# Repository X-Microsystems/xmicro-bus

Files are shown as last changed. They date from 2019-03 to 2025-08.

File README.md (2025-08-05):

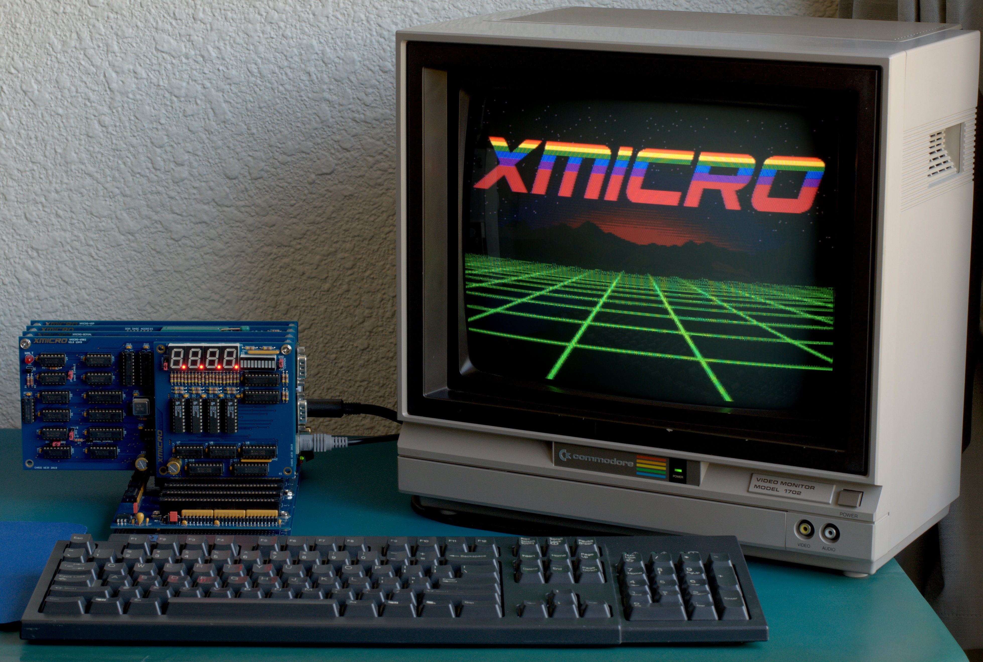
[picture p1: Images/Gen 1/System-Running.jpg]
XMICRO System Running

# XMICRO: A Modular 8-bit Microcomputer System
The XMICRO project began in 2017 as a hobby retrocomputer. Descending from a minimal 6502-based breadboard computer, the decision was made to create a platform which doesn't depend on any particular CPU architecture. In this way, many CPUs could be used for experimentation without the need to create an entire computer system around each one. The name XMICRO, meaning "variable microarchitecture", is a nod toward technology company names of the microcomputer revolution such as Zilog.

In 2020, the project was re-engineered from the ground up. This second generation of hardware improved the performance, reliability, and modularity of all parts of the system.

## Current State
The [XMICRO Bus Specification](Documentation/XMICRO%20Bus%20Specification.pdf) is not yet finalized, however many hardware components have been created which make up a functional 6502-based microcomputer. These include:
* [XMICRO-BP8](https://github.com/X-Microsystems/xmicro-bp8): 8-slot backplane
* [XMICRO-6502](https://github.com/X-Microsystems/xmicro-6502): W65C02 CPU card
* [XMICRO-MEMORY](https://github.com/X-Microsystems/xmicro-memory): 1MB RAM, 8kB ROM primary memory card
* [XMICRO-CF](https://github.com/X-Microsystems/xmicro-cf): CompactFlash storage and RTC card
* [XMICRO-SERIAL](https://github.com/X-Microsystems/xmicro-serial): Dual RS-232 and PS/2 communications card
* [XMICRO-VDP](https://github.com/X-Microsystems/xmicro-vdp): Yamaha V9958 video card

## Generation 2 Hardware Photos
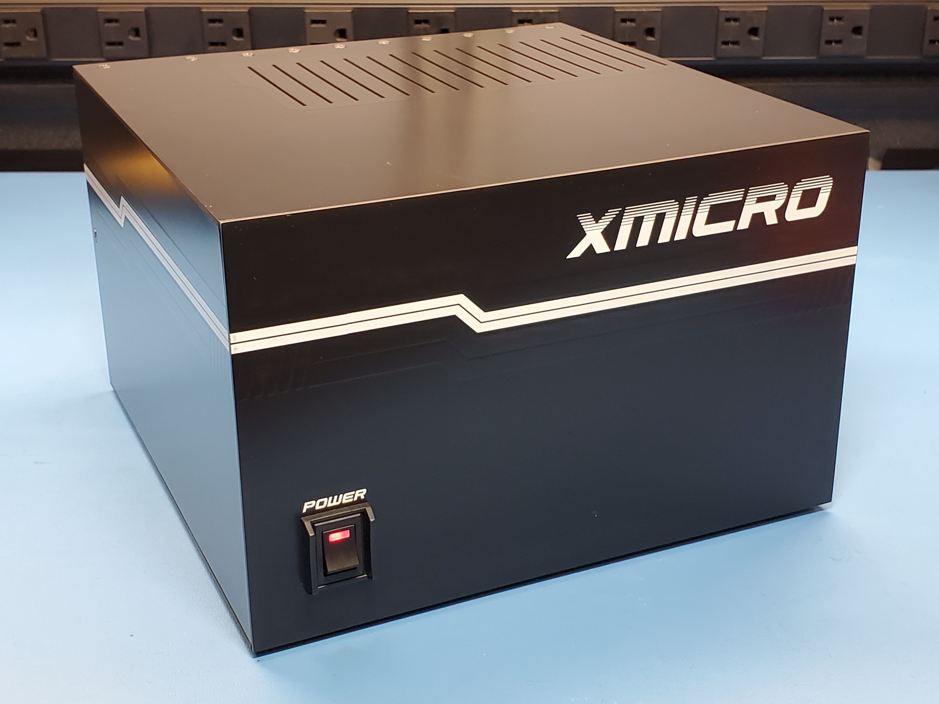
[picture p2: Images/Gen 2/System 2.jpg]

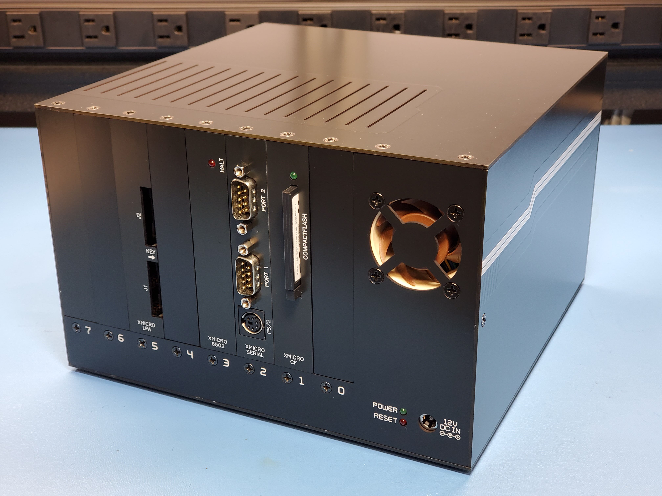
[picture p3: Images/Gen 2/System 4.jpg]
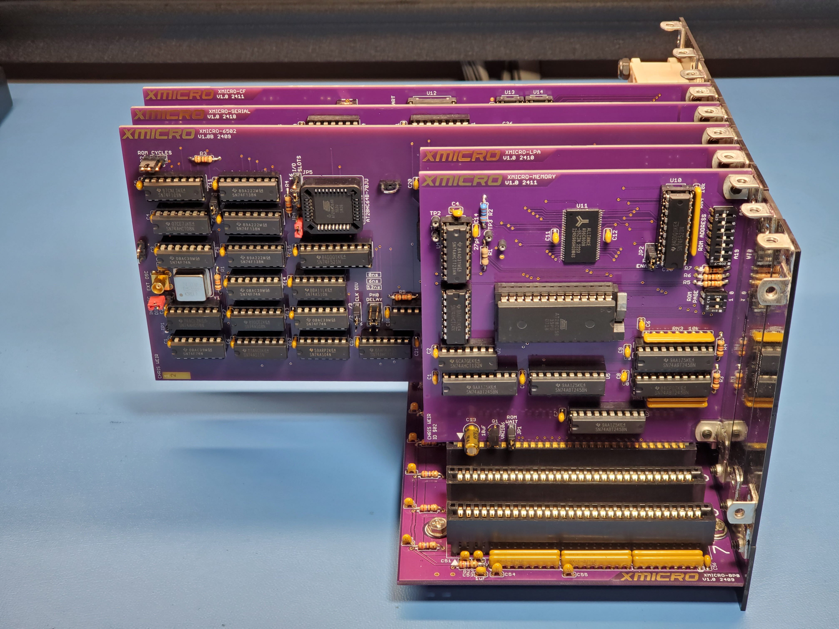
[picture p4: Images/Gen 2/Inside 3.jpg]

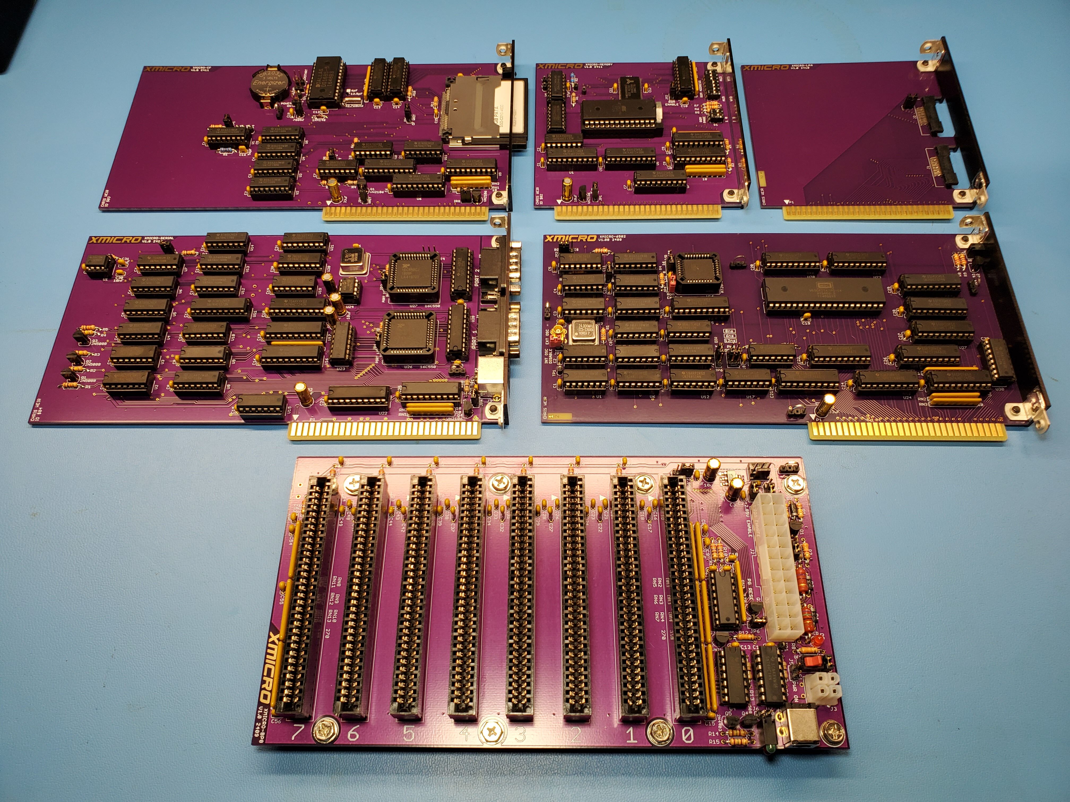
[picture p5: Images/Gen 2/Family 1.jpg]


## Generation 1 Hardware Photos
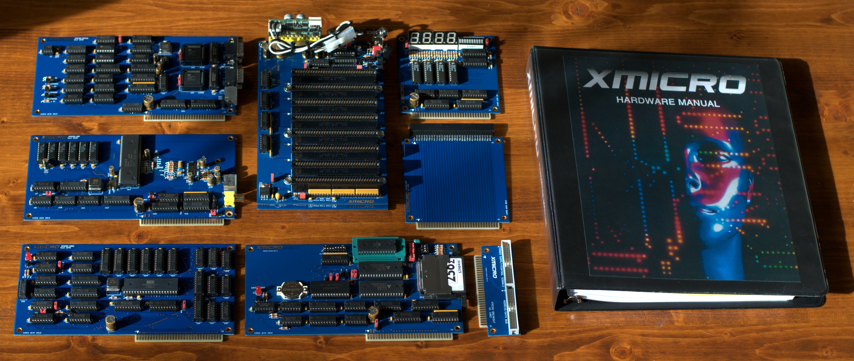
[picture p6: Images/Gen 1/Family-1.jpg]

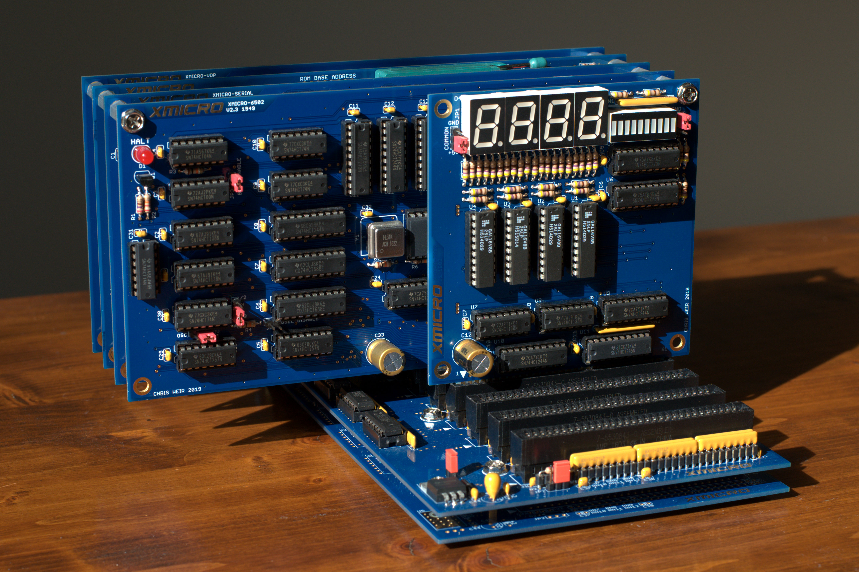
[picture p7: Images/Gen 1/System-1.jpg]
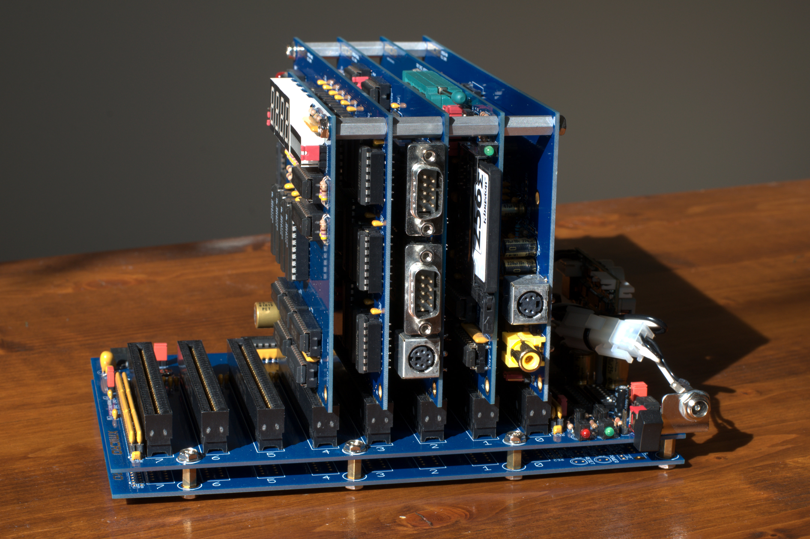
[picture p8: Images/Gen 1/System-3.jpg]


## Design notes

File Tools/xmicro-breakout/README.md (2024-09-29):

# XMICRO-BREAKOUT
Card for breaking out all signals on the [XMICRO bus](https://github.com/x-microsystems/xmicro-bus) to 0.1" pin headers. Can be used with ribbon cables and the included breadboard module for prototyping on a functional system.

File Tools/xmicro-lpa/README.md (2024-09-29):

# XMICRO-LPA

HP/Agilent logic analyzer adapter for the [XMICRO bus](https://github.com/x-microsystems/xmicro-bus). Breaks out all signals to high-density Mictor connectors.

[Datasheet](Documentation/XMICRO-LPA.pdf)

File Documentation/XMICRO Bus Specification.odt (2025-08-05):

Technical Specification

Copyright © 2017-2024 X-Microsystems

Permission is hereby granted, free of charge, to any person obtaining a copy of this specification and associated documentation files (the “Specification”), to deal in the Specification without restriction, including without limitation the rights to use, copy, modify, merge, publish, distribute, sublicense, and/or sell copies of the Specification, and to permit persons to whom the Specification is furnished to do so, subject to the following conditions:

The above copyright notice and this permission notice shall be included in all copies or substantial portions of the Specification.

THE SPECIFICATION IS PROVIDED “AS IS”, WITHOUT WARRANTY OF ANY KIND, EXPRESS OR IMPLIED, INCLUDING BUT NOT LIMITED TO THE WARRANTIES OF MERCHANTABILITY, FITNESS FOR A PARTICULAR PURPOSE AND NONINFRINGEMENT. IN NO EVENT SHALL THE AUTHORS OR COPYRIGHT HOLDERS BE LIABLE FOR ANY CLAIM, DAMAGES OR OTHER LIABILITY, WHETHER IN AN ACTION OF CONTRACT, TORT OR OTHERWISE, ARISING FROM, OUT OF OR IN CONNECTION WITH THE SPECIFICATION OR THE USE OR OTHER DEALINGS IN THE SPECIFICATION.

Tables

Figure 2-1: Read Operation Timing 6

Figure 2-2: Write Operation Timing 6

Figure 2-3: Bus Arbitration Sequence 7

Figure 5-1: Card Physical Dimensions 15

Figure 5-2: Backplane Physical Dimensions 17

Table A-1: Card ID Assignments 19

Figures

Figure 2-1: Read Operation Timing 6

Figure 2-2: Write Operation Timing 6

Figure 2-3: Bus Arbitration Sequence 7

Figure 5-1: Card Physical Dimensions 15

Figure 5-2: Backplane Physical Dimensions 17

# General Description

## Features

- Modular Design
- CPU Architecture Independence
- 8-bit Data Field Width
- 1 Megabyte Memory Address Range
- Discrete I/O Address Range
- Asynchronous Data Transfer
- Multiple Masters
- Automatic Resource Allocation
- Hardware Self-Discovery
- ATX Power Supply Compatibility
- Fully Open-source

## Overview

The XMICRO Bus is a modular platform for building microcomputer systems. Discrete modules called “cards” communicate with one another through this bus over a backplane. Each card slot on the backplane is assigned a 256-byte address space and an interrupt request line. This uniform resource allocation allows most cards to be installed in the system with little or no special hardware configuration. Another advantage of this is the ability to use multiple identical cards in the same system without conflicts. The XMICRO Bus is designed to operate without reliance on any special CPU architecture features, such that most 8-bit microprocessors can be adapted to work with other devices designed for the bus.

An XMICRO system consists of the following elements:

- Backplane
- Primary Master
- Secondary Masters
- Slaves

A Backplane is the basis of any system. In its simplest form, the backplane handles power and signal distribution, decodes I/O addresses, and provides a power-on reset signal. Each backplane contains a number of slots, into which cards may be inserted to build and expand the system. More complex implementations may add significantly more functionality, including peripherals or an onboard CPU.

A Primary Master is a device which acts as the default system controller. Typically this will be the main CPU card. Primary masters must default to this operation unless the bus is requested by another device. Primary masters handle interrupt signals and bus requests. A system must have exactly one primary master installed.

A Secondary Master is a device with the ability to act as a temporary system controller. This is used for direct memory access by the secondary master.

A Slave is a device with no ability to control the system. Slaves are only capable of being read or written to under the command of a master.

Note: The master/slave designation is used only as a broad classification of the functionality of a device. It may be used to refer to either a discrete subsystem or a card as a whole. For example, a coprocessor card may have some control/status registers that can be accessed by the master. Those registers act as a slave device when being read or written to. When the coprocessor later takes control of the bus and directly accesses memory, it is acting as a master.

## Definitions

### System Terminology

Backplane: The central component of the system which provides bus power and signals to all devices

Motherboard: A subtype of backplane containing an integrated Primary Master

Extended backplane: Any backplane with greater than 8 slots

Slot: A uniquely identified position on a backplane where a card may be installed, and the associated set of allocated resources.

Card: A discrete module which interfaces with a backplane through a slot

Master: The current active system controller. This could be either the Primary Master or a Secondary Master

Slave: A device capable of being read or written to by the master.

### Signal Notation

1. Active-low signals are denoted by an OVERLINE.
2. A range of similar signals are referred to collectively using the format A<19..0>. This example is an abbreviation of signals A19 through A0.
3. Table 1-1 lists the terminology used to describe signal states.

Table 1-1: Signal State Terminology

Term | State (Active-high Signal) | State (Active-low Signal)
Asserted | 1, High | 0, Low
Deasserted | 0, Low | 1, High
Released | Z, High-impedance | Z, High-impedance

### Numerical Notation

1. All hexadecimal numbers are indicated by a leading dollar sign ($).
2. All address values are referenced using hexadecimal notation.
3. Numerical digits are substituted with “X” to indicate that any possible value is applicable.
4. I/O resource addresses use a two-digit hexadecimal value formatted as $X00, where X indicates a variable slot number. This notation is used because I/O devices only assess the least-significant eight address bits. See 3.1.2 I/O.
5. Memory addresses use a 5-digit hexadecimal value corresponding to the values of A<19..0>. Example: $01234

# Signaling

## Signal Lines

### Address Lines (A<19..0>)

Twenty unidirectional lines driven by the master to specify a memory or I/O location. Unused address lines must be held at a logic 0 state. Where a master implements bus arbitration (See 2.4 Bus Arbitration), A<19..0> must be capable of entering a high-impedance state.

### Data Lines (D<7..0>)

Eight bidirectional lines which carry information between master and slave devices. See 2.3 Data Transfers.

### Read Strobe (RD)

Asserted by the master to indicate that the addressed slave device may place data on the data lines. The data bus is read by the master at the rising edge of RD. See 2.3 Data Transfers.

### Write Strobe (WR)

Asserted by the master to indicate that it has placed data on the data lines. The data bus should be read by the addressed slave device at the rising edge of WR. See 2.3 Data Transfers.

### I/O Select (IOSEL)

Asserted by the master to access the backplane’s card I/O address space. When asserted, A<19..8> determine which backplane slot is being addressed, and the backplane asserts the CSX signal for that slot. See 3.1 Address Spaces.

### Card Select – Slot X (CSX)

This slot-specific signal is driven by the backplane to indicate that the I/O address space is selected, and the current address is within the range of the slot’s allocated I/O address space. While this signal is asserted, A<19..8> may be ignored by the slave card because their state is known. This is a discrete signal for each card slot. See 2.2 Address Signaling and 3.1 Address Spaces.

### Main Memory Inhibit (INH)

This open-collector signal is used to inhibit general-purpose main memory. When INH is asserted, main memory must be prevented from reading or writing data, or driving the bus. This allows cards to make special-purpose memory available without reconfiguring or replacing the entire memory system. As this signal is typically derived from and therefore becomes stable after other Group A signals, its use may necessitate additional bus cycle time. INH has no effect on I/O operations. See 3.1.1 Memory.

### Wait (WAIT)

This open-collector line is asserted by the addressed slave device to indicate that the data transaction in progress is not yet ready to be completed. If WAIT is asserted concurrently with RD or WR, the master must hold all of its Group A signals in their current state until after WAIT is released. It is recommended that devices requiring greater than 100ns access time use this signal. See 2.3 Data Transfers.

### Reset (RST)

This open-collector signal resets the system and initializes it to a predictable state. During the power-on sequence, this signal should be asserted by the backplane until at least 100ms after all power supply rails have stabilized. RST may be used by any device for initialization.

### Bus Request (BUSRQ)

This open-collector signal is asserted by a secondary master to request control of the bus. When the primary master is ready to release control of the bus, it will assert BUSAK. See 2.4 Bus Arbitration.

### Bus Acknowledge (BUSAK)

This signal is asserted by the primary master to indicate that it has released all Group A bus signals for control by a secondary master. The secondary master may only control the bus while this signal is asserted. See 2.4 Bus Arbitration.

### Halt (HALT)

This status line is asserted by the primary master to indicate to that it is in a halted state and waiting for an interrupt. Not to be confused with WAIT.

### Interrupt Request – Slot X (IRQX)

This slot-specific line is asserted by a card to indicate that it requires the primary master’s attention. This allows for interrupt vectoring and prioritization based on card position. This is a level-triggered interrupt signal. This is a discrete signal for each card slot. See 2.5.1 Level-triggered Interrupts.

### Summary Interrupt (SINT)

This open-collector signal is asserted by the backplane while any IRQX line is asserted. Therefore, this is a level-triggered interrupt signal. This signal is provided by the backplane and is not to be driven directly by a card.

### Vectored Interrupt Lines (V<7..0>)

These eight lines correspond to the IRQX signal of slots 7..0 on a backplane. They are used by the primary master for interrupt prioritization and vectoring. A primary master may accept these signals as discrete interrupts from the first eight slots. These signals are provided by the backplane and are not to be driven directly by a card. See 3.3.1 Vectored Interrupts.

### Non-maskable Interrupt (NMI)

Open-collector edge-triggered interrupt signal. Its implementation may vary considerably between primary masters, so it is recommended that this signal be optional on any card using it. NMI should only be used for special signals requiring the immediate attention of the primary master and priority over all other interrupts. Some examples could be memory errors, power failure, or video timing. See 2.5.2 Edge-triggered Interrupts and 3.3.2 Non-maskable Interrupt.

### System Clock (CLK)

This signal is the main system clock. Care should be taken to ensure it is a clean square wave. Its frequency and duty cycle are not defined. The primary master should typically provide this signal, however it may optionally be provided by another card such as a video card. It is recommended that primary masters do not strictly require externally generated clock signals to function. Any card capable of driving this signal must have an option to disable it, to prevent conflicts with other cards. Use of this signal for purposes that may restrict the system’s compatibility with other devices is strongly discouraged.

### Instruction Fetch (FETCH)

This signal is asserted by the primary master to indicate that the current read/write operation is an instruction fetch. This can be used by coprocessors or debuggers for synchronization and analysis. Implementation of this signal is optional.

### Power Supply Rails (+12V, +5V, +5VSB +3.3V, 0V, -12V)

These non-signal lines supply power to the bus. Current capacity is defined by the individual backplane’s specifications, as well as 4.2 Connectors. See 4.3 Power Supply.

Table 2-1: Signal Sources

Group | Signal | Driver | Receiver
A Information | A<19..0> | Master | Any
| D<7..0> | Master (WR), Slave (RD) | Slave (WR), Master (RD)
| RD | Master | Any
| WR | Master | Any
| IOSEL | Master | Backplane, Memory Systems
| CSX | Backplane | Cards
| INH | Any | Memory Systems
B Control | WAIT | Slave | Master
| RST | Any | Any
| BUSRQ | Secondary Master | Primary Master
C Status | BUSAK | Primary Master | Secondary Master
| HALT | Primary Master | Any
| FETCH | Primary Master | Any
| CLK | Master (Typically) | Any
D Interrupt | IRQX | Any | Primary Master
| SINT | Backplane | Primary Master
| V<7..0> | Backplane | Primary Master
| NMI | Any | Primary Master
E Supply | +12V | Backplane | Any
| +5V | Backplane | Any
| +5VSB | Backplane | Any
| +3.3V | Backplane | Any
| 0V | Backplane | Any
| -12V | Backplane | Any

## Address Signaling

Table 2-2 contains a sample of address signal relationships. A<19..0> and IOSEL are driven by the master, and CSX signals are asserted by the backplane in response. See 3.1 Address Spaces.

Table 2-2: Address Signal Relationships

A<19..0> | IOSEL | CSX (Slot 0) | CSX (Slot 1) | CSX (Slot 2)
$XXXXX | 1 | 1 | 1 | 1
$000XX | 0 | 0 | 1 | 1
$001XX | 0 | 1 | 0 | 1
$002XX | 0 | 1 | 1 | 0

## Data Transfers

Data are transferred asynchronously in 8-bit words (bytes). RD/WR may only be asserted while the address lines A<19..0>, IOSEL, and CSX are valid and stable, and must never be asserted simultaneously. During a read operation, the addressed slave places data on D<7..0>, which is read by the master at the rising edge of RD. During a write operation, the master places data on D<7..0>, which is read by the slave at the rising edge of WR.

The addressed slave may optionally assert WAIT during a data transfer to temporarily pause the sequence until it is ready to send or receive data. During this time, the master must not change the state of A<19..0>, IOSEL, CSX, RD, WR, or D<7..0>. When WAIT is high, the master may complete the transfer sequence.

Table 2-3: Data Transfer Timing Parameters

No. | Symbol | Parameter | Min. | Max.
1 | Tas | Address setup time prior to RD/WR falling edge | 10ns | —
2 | Tah | Address hold time after RD/WR rising edge | 10ns | —
3 | Tds | Data setup time prior to RD/WR rising edge | 20ns | —
4 | Tdhr | Data hold time after RD rising edge | 10ns | 30ns
5 | Tdhw | Data hold time after WR rising edge | 10ns | 30ns
6 | Twl | WAIT falling edge delay after RD/WR falling edge | 0ns | 40ns
7 | Twh | RD/WR rising edge delay after WAIT rising edge | 0ns | —

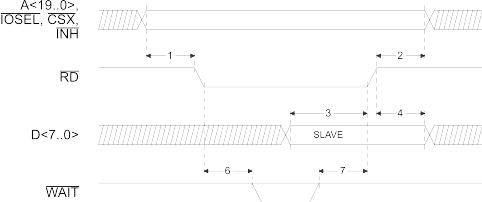
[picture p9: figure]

Figure 2-1: Read Operation Timing

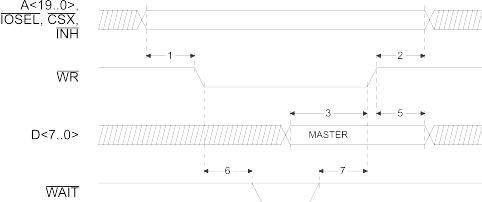
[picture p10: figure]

Figure 2-2: Write Operation Timing

## Bus Arbitration

In the system’s default state, the primary master has full control of the system bus. By asserting the BUSRQ line, a secondary master may request to temporarily take over control of some signals in order to directly access memory or I/O devices. When BUSRQ is asserted, the primary master gracefully hands over control of Group A signals.

The BUSAK signal indicates that the primary master has placed its Group A signals in a high-impedance state. These signals may be driven by a secondary master only while BUSAK is asserted. In order to prevent invalid data transfers, the primary master must remain in this high-impedance state until BUSRQ is released.

To avoid bus contention, secondary masters should wait for a command from the primary master before initiating a bus request, and must not initiate a bus request until the BUSRQ signal is no longer asserted by another device.

A typical bus arbitration sequence is as follows:

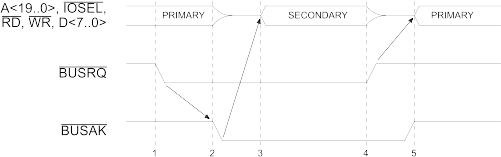
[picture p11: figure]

Figure 2-3: Bus Arbitration Sequence

1. A secondary master asserts the BUSRQ line.
2. The primary master, at its discretion, releases its Group A signals and asserts BUSAK.
3. The secondary master begins driving its Group A signals.
4. The secondary master, at its discretion, releases its Group A signals and releases BUSRQ.
5. The primary master deasserts BUSAK and resumes driving its Group A signals.

## Interrupts

Each card’s interrupt signals must default to a disabled state upon reset, such that they must be enabled through software before the card will assert them.

### Level-triggered Interrupts

Level-triggered interrupt signals (IRQX, V<7..0>, SINT) must be asserted by a device until it no longer requires the primary master’s attention. A level-triggered interrupt signal which has been asserted and released before it was serviced may be disregarded.

### Edge-triggered Interrupts

Edge-triggered interrupt signals (NMI), as the name implies, are only sensitive to a falling edge. The state of the signal has no bearing on whether an edge-triggered interrupt should be serviced.

# System Operation

## Address Spaces

The system is divided into two discrete address spaces – “Memory” and “I/O”.

1. When IOSEL is not asserted, the memory address space is selected and read/write operations apply to memory devices.
2. When IOSEL is asserted, the I/O address space is selected and read/write operations apply to I/O devices.

### Memory

There are two types of memory that can be added to a system:

1. “Main Memory” is memory that is accessible when INH is not asserted. It is recommended that only one device manages main memory in a system. Main memory is typically populated with general-purpose RAM.
2. “Override Memory”, when it is addressed, asserts the INH signal to disable main memory devices occupying the desired location. In this way, specialized memory devices may be added to a system without the need to reconfigure the main memory subsystem. In cases where INH is used, the main memory located at those addresses should be considered invalid.

### I/O

1. Each card slot on a backplane is assigned 256 bytes of I/O address space, beginning at I/O address $00000. Each 256-byte block of I/O addresses is assigned to a slot number equal to the value of A<19..8>. For example, Slot 0 addresses are located from $00000-$000FF, Slot 1 from $00100-$001FF, etc.
2. When a slot’s I/O block is addressed by the master, the backplane asserts the CSX signal for that card.
3. CSX indicates to a slave that it is being addressed, and that A<7..0> contain the address to be accessed. Slave devices may only use A<7..0> for addressing purposes, and A<19..8> must be ignored by slaves during I/O operations.
4. A backplane’s I/O decoding logic must ignore any I/O address bits that are not required to access the number of implemented slots.

## Reserved Addresses

Addresses $XFC-$XFF are reserved for special bus functions. These should not be used except as described in Table 3-1.

Table 3-1: Reserved Addresses

Address | Purpose
$XFC | Reserved
$XFD | Reserved
$XFE | Reserved
$XFF | Card ID

### Card IDs

Each card should present an identification value at address $XFF which is unique to that type of card within the system. Identical cards should have identical IDs. Cards may be assigned a permanent ID as part of the XMICRO bus specification. Refer to Appendix A for Card ID assignments.

## Interrupts

Interrupts provide cards with a means of requesting the attention of the primary master. Since interrupt schemes vary considerably between CPUs, the implementation of interrupts in an XMICRO system is relatively loosely defined.

When an interrupt signal is asserted, it is expected that the primary master will respond to it as soon as possible. Table 3-2 lists all interrupt signals on the bus, in order from highest to lowest priority. When multiple interrupt signals are being asserted simultaneously, they should be assessed in order from highest to lowest priority.

Table 3-2: Interrupt Signal Priority

Signal | Priority
NMI | Highest
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
SINT | Lowest

### Vectored Interrupts

IRQX is asserted by cards as a general-purpose interrupt request. While any card’s IRQX line is asserted, SINT is also asserted by the backplane as a summary of all interrupt requests.

Signals V<7..0> are connected on the backplane to the corresponding IRQX of slot 7..0. On extended backplanes, implementation of IRQX on slot 8 and higher is optional. The backplane may use IRQX on these slots to assert a summary interrupt (SINT) with no vector signals (V<7..0>) asserted.

### Non-maskable Interrupt

NMI is a special interrupt intended for timing-sensitive operations. It has a higher priority than any other interrupt. Where possible, a primary master should immediately respond to an NMI, including interrupting an in-progress interrupt service routine. No other interrupts should interrupt an NMI service routine.

Due to hardware limitations, some primary masters may not be capable of overriding an interrupt routine in progress. In this case, NMI should be serviced as soon as possible.

# Electrical Specifications

## Signal Lines

### Signal Characteristics

1. A receiver must recognize a voltage of ≤ 0.8V as a logic 0, and a voltage of ≥ 2.0V as a logic 1.
2. The minimum sink current capability of any driver on any line must be 20mA at 0.5V. Further, it is recommended that drivers with minimum source capability of 20mA at 2.4V be used.

Table 4-1: Bus Driver and Receiver Characteristics

Signal | Driver Topology | Receiver Hysteresis
A<19..0> | Tri-state | Not Required
D<7..0> | Tri-state | Not Required
RD | Tri-state | Not Required
WR | Tri-state | Not Required
IOSEL | Tri-state | Not Required
CSX | Push-pull | Not Required
BUSAK | Push-pull | Not Required
HALT | Push-pull | Not Required
FETCH | Push-pull | Not Required
CLK | Push-pull | Not Required
INH | Open-collector | Required
WAIT | Open-collector | Required
RST | Open-collector | Required
BUSRQ | Open-collector | Required
NMI | Open-collector | Required
IRQX | Open-collector | Not Required
SINT | Open-collector | Not Required
V<7..0> | Open-collector | Not Required

### Signal Integrity

For all signal lines, care must be taken to maintain high-speed signal integrity.

1. A card should add no more than 2” of total conductor length to any bus signal.
2. A card should present no more than 25pF capacitance to any bus signal.

### Termination

1. When no device is driving a bus line, that line must be pulled to a high state by the backplane.
2. The combined DC current of all bus terminations must not exceed 22mA on any signal line.
3. The recommended active termination scheme for all bus signal lines is a 270Ω resistor to +2.85V at each end of the backplane.

## Connectors

### Backplane Interconnects

1. Backplanes must be fitted with female 62-position dual-row card edge connectors with a 0.1” contact pitch, designed for 0.0625” card thickness. TE Connectivity 7-5530843-0 or equivalent is recommended. Each of these connectors is considered a discrete slot.
2. Cards must be fitted with male card-edges compatible with the specified backplane connectors and conforming to physical specifications outlined in 5.1 Cards.
3. The average current on any backplane connector pin must not exceed 2A. The recommended maximum current on backplane connectors is 1A for supply pins and 100mA for all other pins. If lower than these values, maximum design current for each rail must be specified in the included documentation for a backplane, or on the backplane PCB.
4. No XMICRO bus signal may be delivered between any two devices except by these backplane interconnects.

Table 4-2: Backplane Interconnect Pinout

Pin | Signal | Pin | Signal
1 | +12V | 2 | +3.3V
3 | 0V | 4 | 0V
5 | +5V | 6 | +5V
7 | -12V | 8 | +5VSB
9 | CSX | 10 | RST
11 | BUSRQ | 12 | BUSAK
13 | CLK | 14 | FETCH
15 | HALT | 16 | WAIT
17 | INH | 18 | IOSEL
19 | RD | 20 | WR
21 | 0V | 22 | A0
23 | A1 | 24 | A2
25 | A3 | 26 | A4
27 | A5 | 28 | A6
29 | A7 | 30 | A8
31 | A9 | 32 | A10
33 | A11 | 34 | A12
35 | A13 | 36 | A14
37 | A15 | 38 | A16
39 | A17 | 40 | A18
41 | A19 | 42 | 0V
43 | D0 | 44 | D1
45 | D2 | 46 | D3
47 | D4 | 48 | D5
49 | D6 | 50 | D7
51 | SINT | 52 | IRQX
53 | V0 | 54 | V1
55 | V2 | 56 | V3
57 | V4 | 58 | V5
59 | V6 | 60 | V7
61 | NMI | 62 | 0V

### Supplemental Power

Supplemental power may be delivered using TE Connectivity 174804-1 (Male) or equivalent installed on cards. Pinout and current limits match ATX standards for peripheral connectors.

Table 4-3: Supplemental Power Connector Pinout

Pin | Signal
1 | +12V
2 | 0V
3 | 0V
4 | +5V

## Power Supply

### Main Power Supply

1. A backplane must supply cards with the following voltages: +12V, +5V, +5VSB, 0V, -12V.
2. Specifications of the supply rails must meet ATX power supply standards.
3. The use of an ATX-compatible power supply is recommended.

### Supplemental Power Supplies

Cards may use an additional connector to supplement the +12V, +5V, and 0V rails. Where such a connector is used, the following requirements apply:

1. All supplemental power rails must match the potential of the bus rails such that no significant current flows between them.
2. Supplemental power must be delivered using connectors as specified in 4.2.2 Supplemental Power.

## Grounding

### Signal Ground

The 0V supply rail serves as the 0V reference and return path for all bus signals and supply rails.

### Chassis Ground

1. A separate chassis ground must be maintained for conductive chassis members. The purpose of the chassis ground is to provide a safe, low-impedance return path for ESD and electrical faults, as well as to avoid stray ground paths between cards which could result in unpredictable operation.
2. Where mechanical mounting holes in cards can be used to make an electrical connection to chassis members or other cards, those holes must be isolated from the 0V supply rail. Mechanical mounting holes are not required to be electrically connected to each other.
3. Where connectors have a separate shield conductor that is not used as a signal ground, the shield should be tied to chassis ground. It is recommended that connector shields be electrically connected to the rear-edge mounting holes of the card.
4. Chassis ground should be tied to the signal ground at the backplane.

# Physical Specifications

## Cards

1. A card’s dimensions must not exceed the overall dimensions shown in Figure 5-1.
2. Card edge connectors must match the dimensions shown in Figure 5-1.
3. Pin 1 of the edge connector must be indicated on the card.
4. Card edge connectors should be gold-plated for reliability. HASL or similar soft surface finishes are discouraged.
5. Card edge connectors should be chamfered for easier insertion.
6. The use of standard “full-size” and “half-size” card form-factors shown in Figure 5-1 is strongly encouraged.
7. Standard card mounting holes should be isolated from the backplane’s 0V pins and treated as a discrete chassis ground if conductive. See 4.4.2 Chassis Ground.
8. External I/O connectors may only be placed on the rear edge.

## Backplanes

1. Backplanes must conform to the measurements and orientation shown in Figure 5-2.
2. Pin 1 must be indicated on at least one slot.
3. Each slot’s number must be indicated on the PCB
4. Maximum component height under cards may not exceed the edge connectors
5. All backplane slots must be capable of receiving maximum-dimension cards

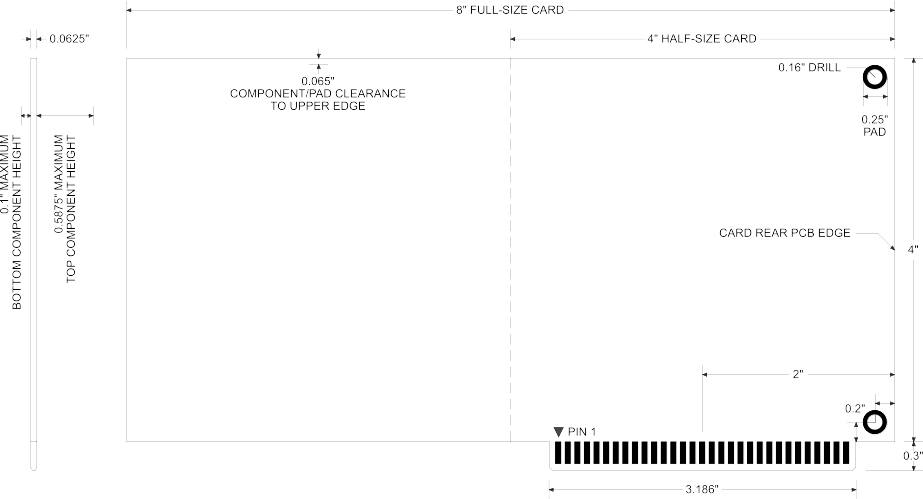
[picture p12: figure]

Figure 5-1: Card Physical Dimensions

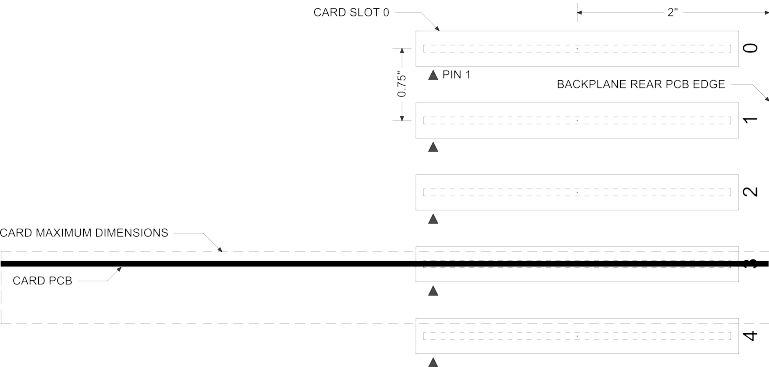
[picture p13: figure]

Figure 5-2: Backplane Physical Dimensions

##### Card IDs

1. IDs $00 and $FF are reserved to indicate that no card is installed in the addressed slot.
2. IDs $E0-$FE will not be assigned to any specific devices and may be used for any device that has not been granted a permanent ID.
3. Any ID not listed in Table A-1 is not currently assigned and may not be used.

Table A-1: Card ID Assignments

Value | Device
$00 | Reserved (No card detected)
$01 | XMICRO-6502
$02 | XMICRO-MEMORY
$03 | XMICRO-CF
$04 | XMICRO-SERIAL
$05 | XMICRO-VDP
$06 | XMICRO-7SEG
$E0-$FE | Open for any use
$FF | Reserved (No card detected)

PRELIMINARY This page is intentionally left blank.

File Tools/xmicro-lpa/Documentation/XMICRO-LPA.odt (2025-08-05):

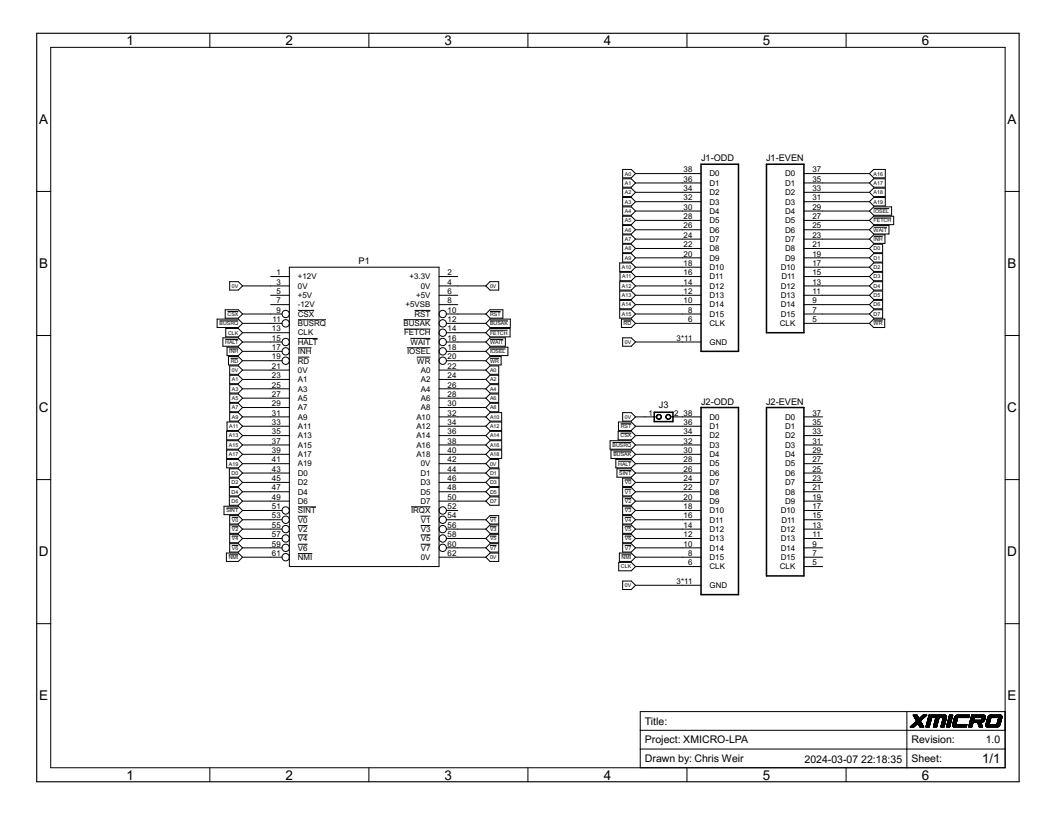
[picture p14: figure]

# General Description

The XMICRO-LPA is an XMICRO development tool which breaks out all bus signals into high-density connectors compatible with HP/Agilent logic analyzers.

## Features

- For use with HP/Agilent E5346A High Density Probe Adapter
- Minimal skew on critical signals

## System Outline

Signal Length (mm) Total Delay (ps) Skew (ps) D5 66.42 380.80 -7.74 D6 66.69 382.35 -6.19 D7 66.79 382.92 -5.62 D2 66.90 383.55 -4.99 V7 67.04 384.36 -4.19 A11 67.13 384.87 -3.67 D3 67.17 385.10 -3.44 A14 67.18 385.16 -3.38 D4 67.21 385.33 -3.21 A13 67.29 385.79 -2.75 A5 67.29 385.79 -2.75 A15 67.29 385.79 -2.75 A1 67.38 386.30 -2.24 A6 67.40 386.42 -2.12 A10 67.40 386.42 -2.12 D0 67.43 386.59 -1.95 A2 67.49 386.94 -1.61 A9 67.51 387.05 -1.49 A7 67.51 387.05 -1.49 A4 67.55 387.28 -1.26 A12 67.55 387.28 -1.26 A0 67.58 387.45 -1.09 D1 67.65 387.85 -0.69 A3 67.66 387.91 -0.63 NMI 67.77 388.54 0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 | Signal Length (mm) Total Delay (ps) Skew (ps) RD 67.77 388.54 0.00 WR 67.77 388.54 0.00 A8 67.77 388.54 0.00 A18 67.89 389.23 0.69 A19 68.03 390.03 1.49 V6 68.42 392.27 3.73 A17 68.56 393.07 4.53 A16 68.70 393.87 5.33 INH 69.52 398.57 10.03 V5 70.85 406.20 17.66 WAIT 71.57 410.33 21.79 V4 72.23 414.11 25.57 IOSEL 72.54 415.89 27.35 FETCH 74.38 426.44 37.90 V3 74.66 428.04 39.50 V2 76.04 435.95 47.41 V1 78.47 449.89 61.35 V0 79.85 457.80 69.26 SINT 81.23 465.71 77.17 CLK 87.07 499.19 110.65 HALT 90.02 516.10 127.56 BUSAK 93.51 536.11 147.57 BUSRQ 94.89 544.03 155.48 CSX 97.32 557.96 169.42 RS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

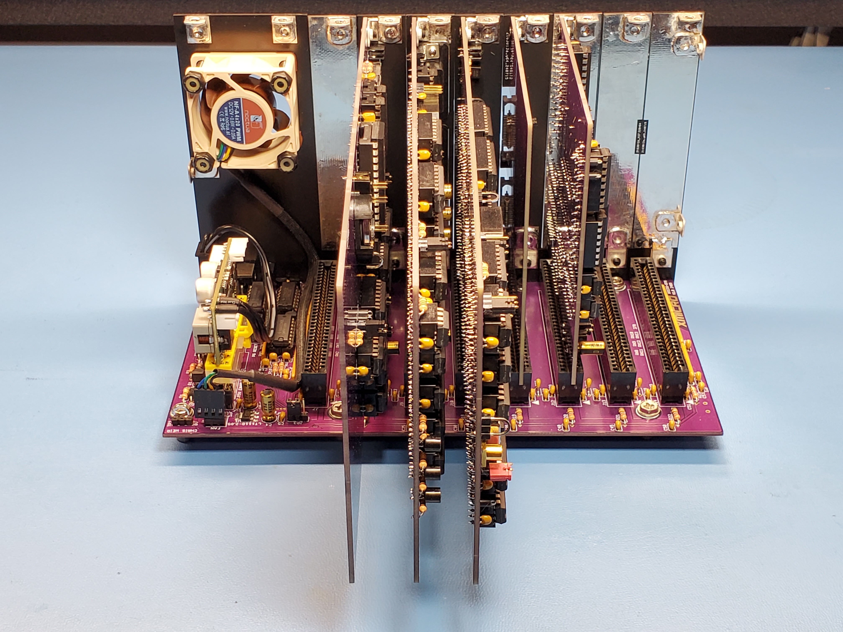
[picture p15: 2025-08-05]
Images/Gen 2/Inside 4.jpg

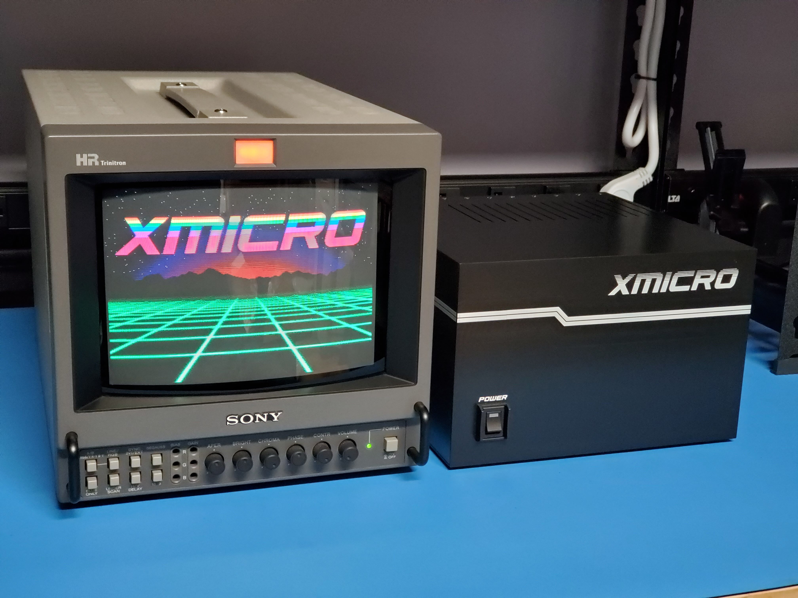
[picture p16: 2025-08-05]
Images/Gen 2/Display 4.jpg

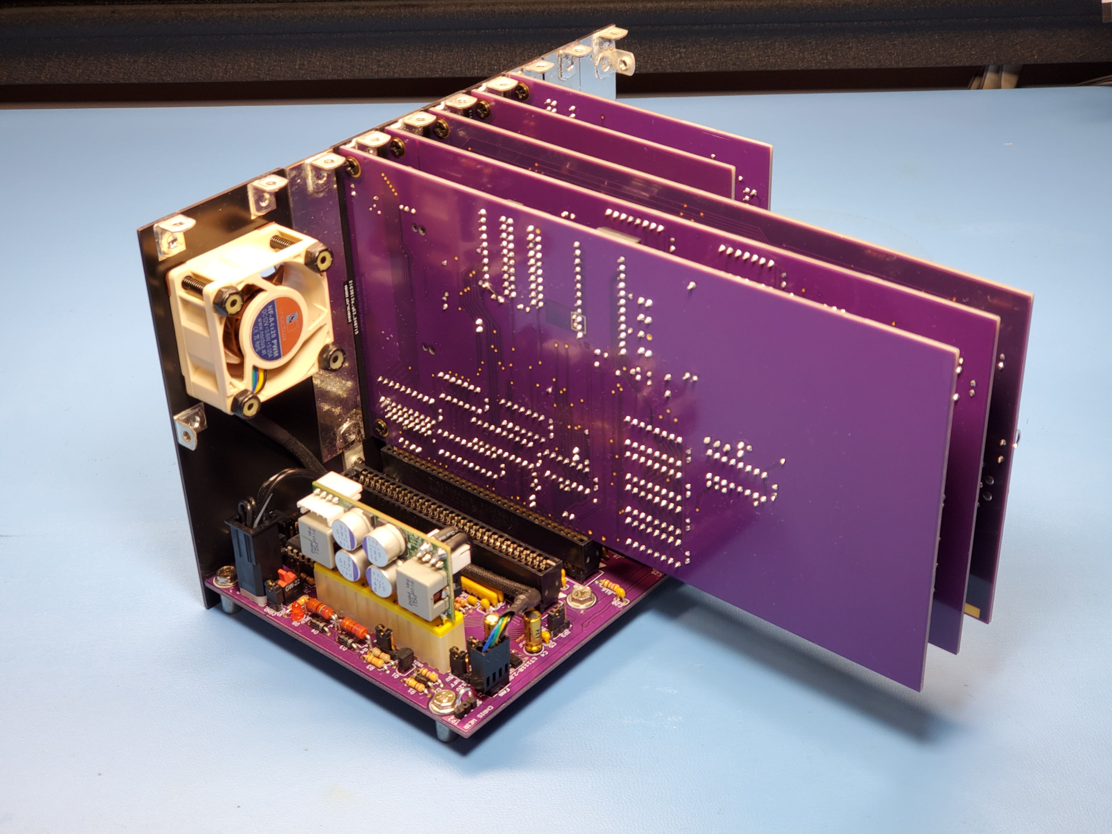
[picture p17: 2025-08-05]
Images/Gen 2/Inside 5.jpg

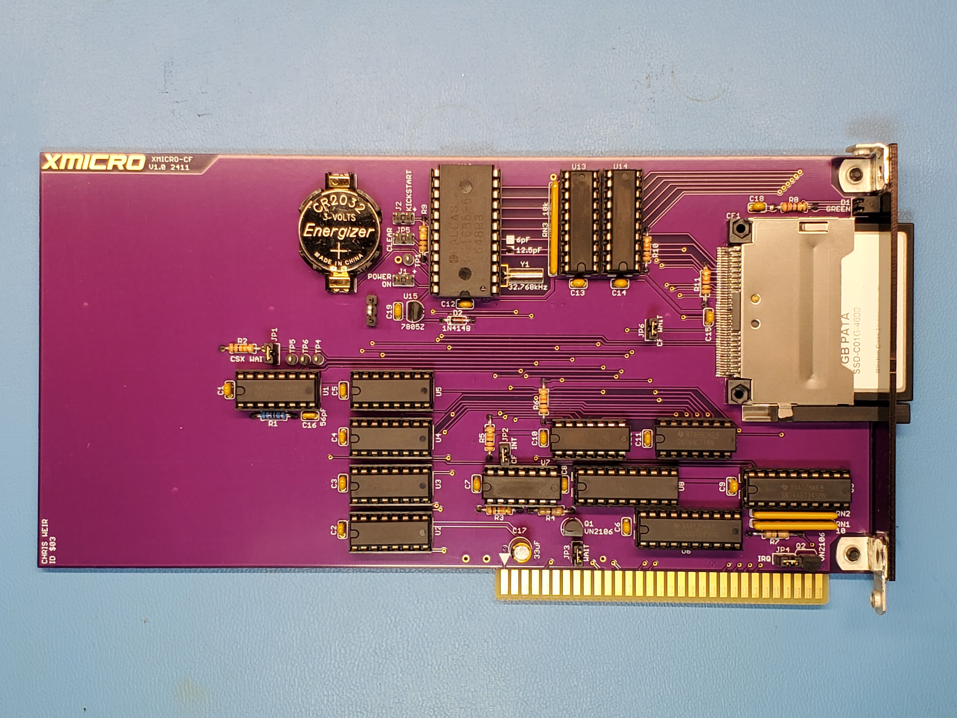
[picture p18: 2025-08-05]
Images/Gen 2/XMICRO-CF 1.jpg

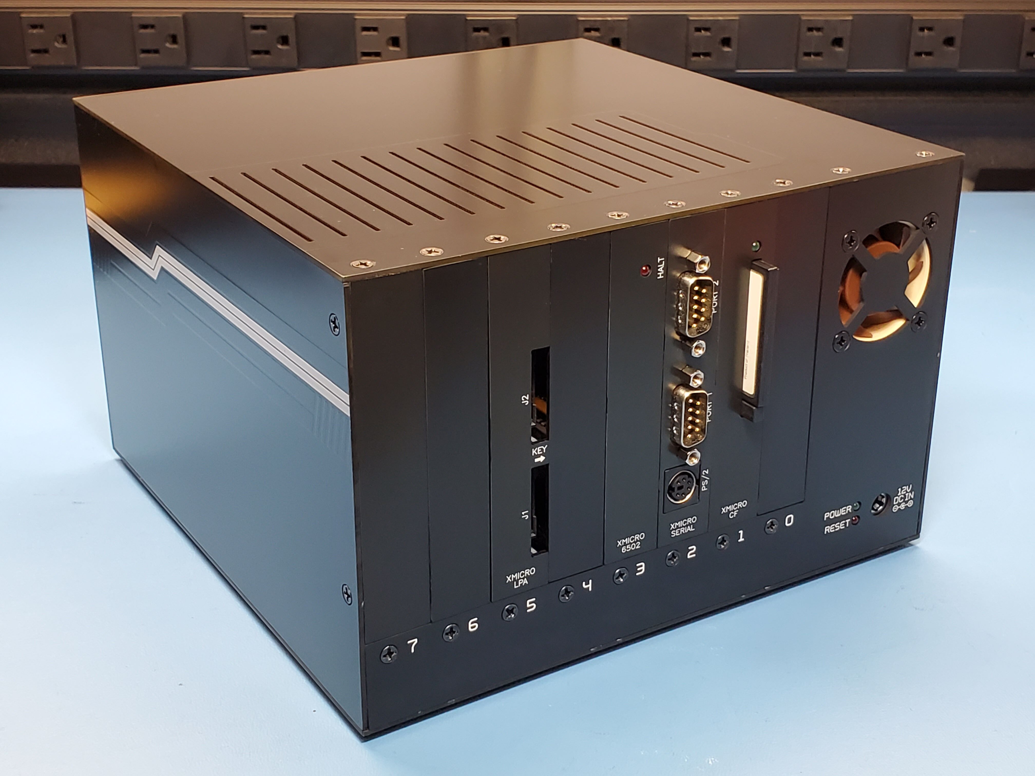
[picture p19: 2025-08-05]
Images/Gen 2/System 5.jpg

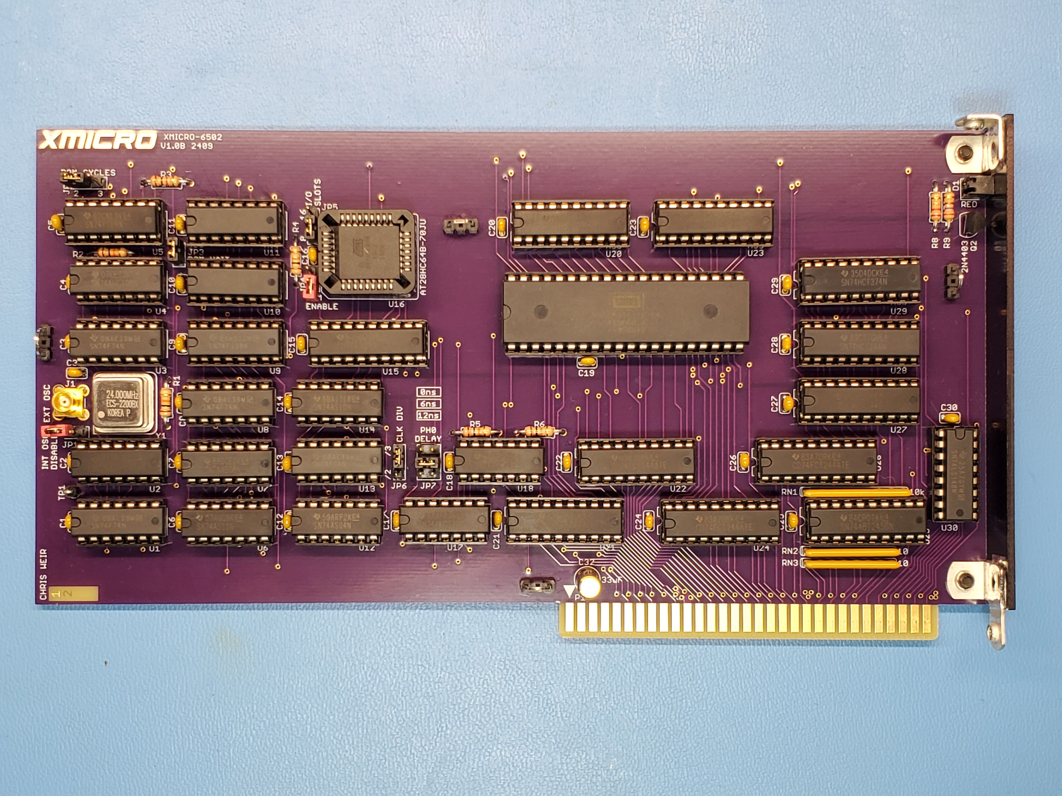
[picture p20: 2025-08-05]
Images/Gen 2/XMICRO-6502 1.jpg

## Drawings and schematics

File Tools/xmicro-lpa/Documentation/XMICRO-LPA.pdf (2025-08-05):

# XMICRO-LPA

2024-09-29 | Hardware V1.0 2411

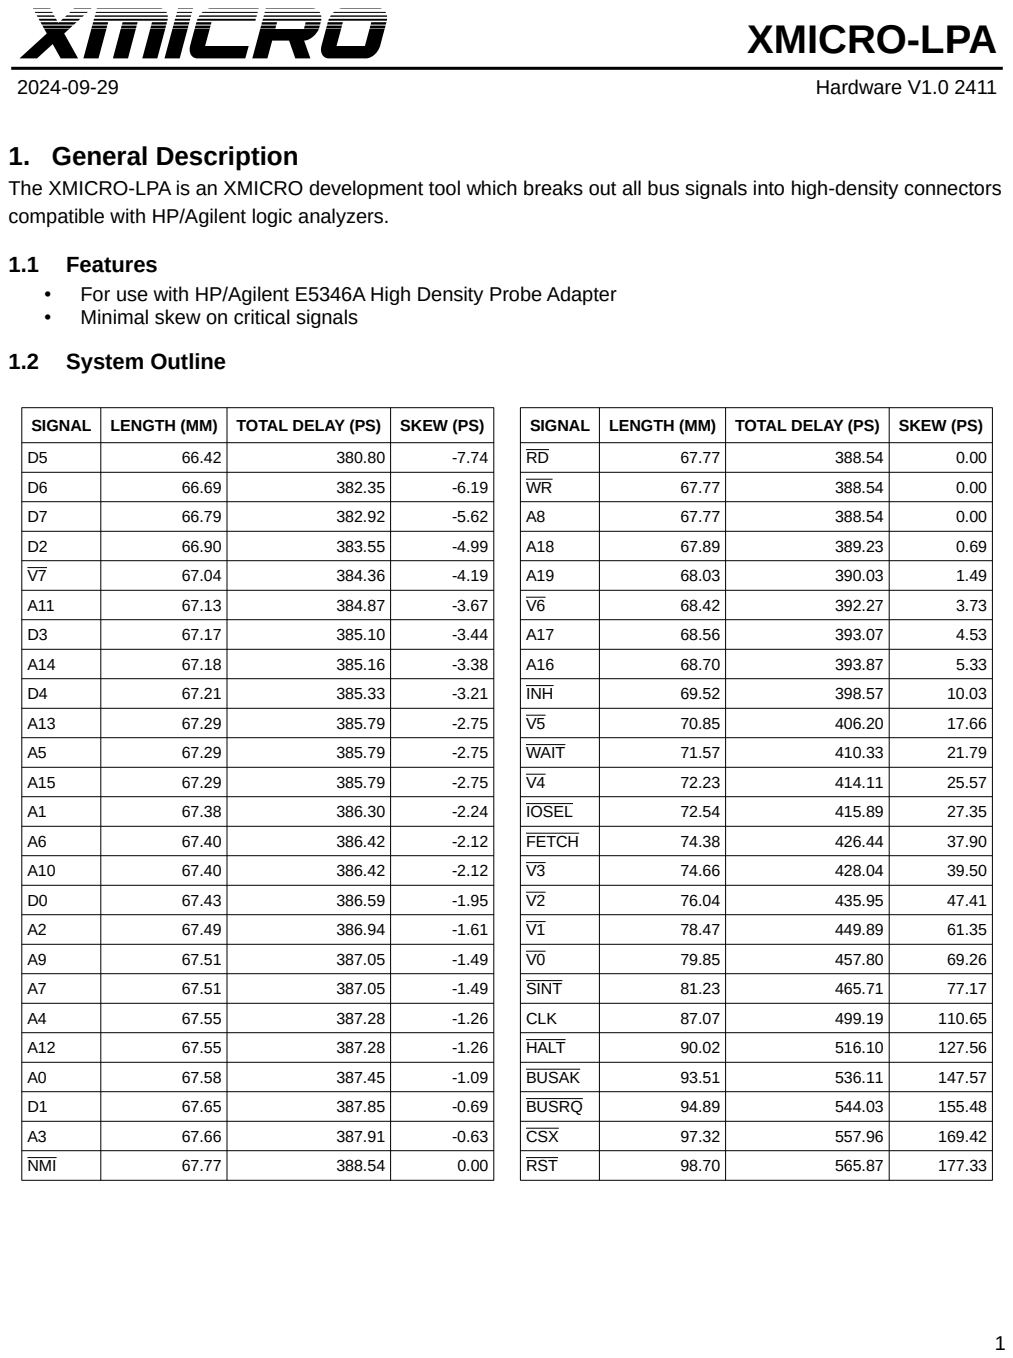
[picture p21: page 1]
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

compatible with HP/Agilent logic analyzers.

• For use with HP/Agilent E5346A High Density Probe Adapter
• Minimal skew on critical signals

A

A

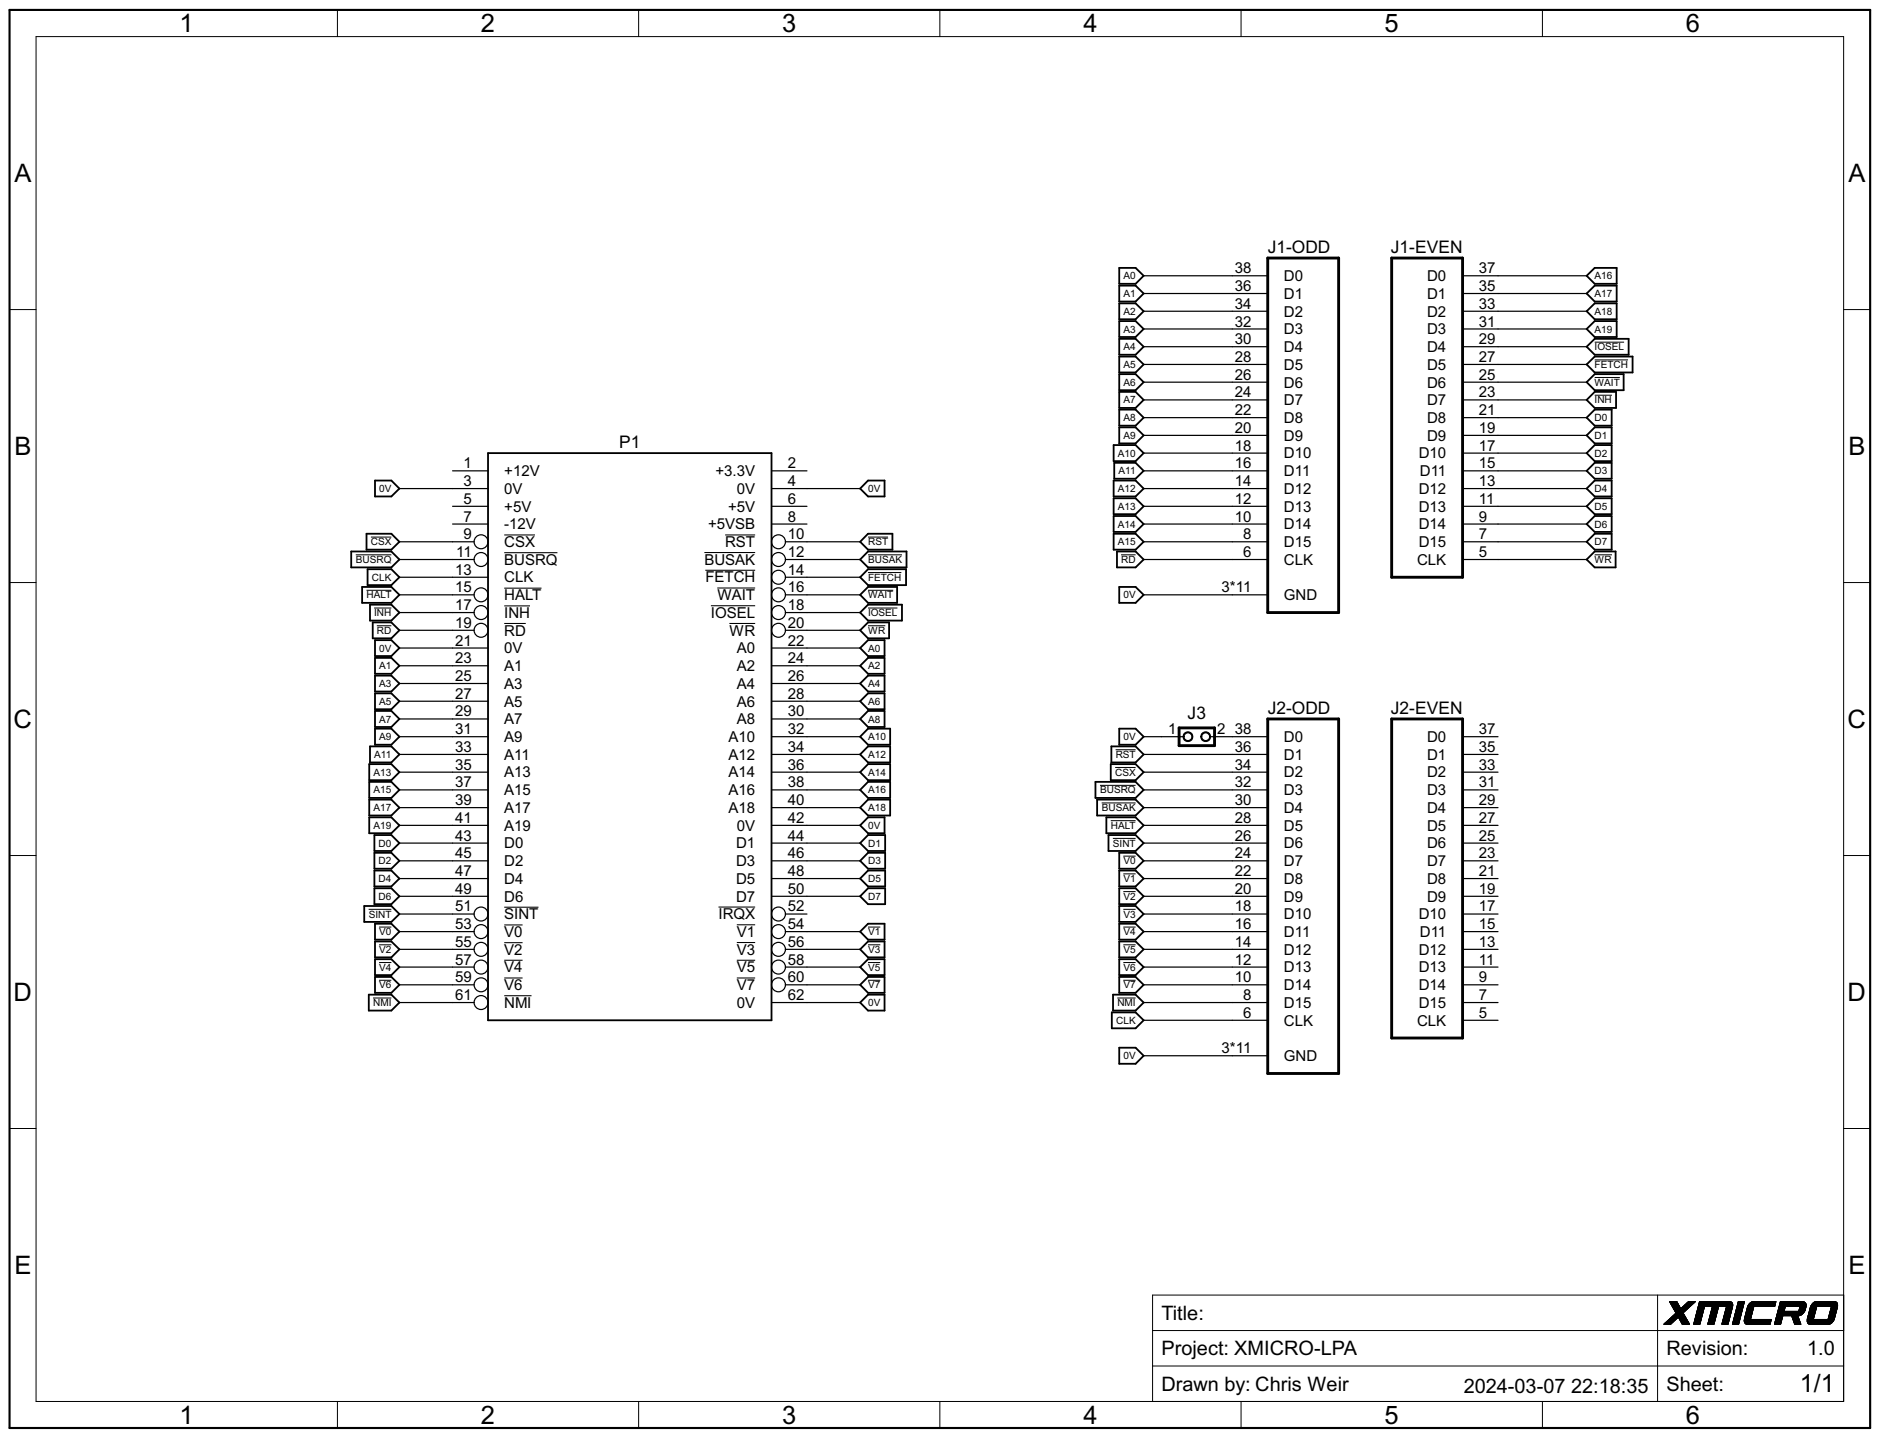
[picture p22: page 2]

Title: Project: XMICRO-LPA | Revision: Chris Weir Sheet: 1/1 1.0

Drawn by: 2024-03-07 22:18:35

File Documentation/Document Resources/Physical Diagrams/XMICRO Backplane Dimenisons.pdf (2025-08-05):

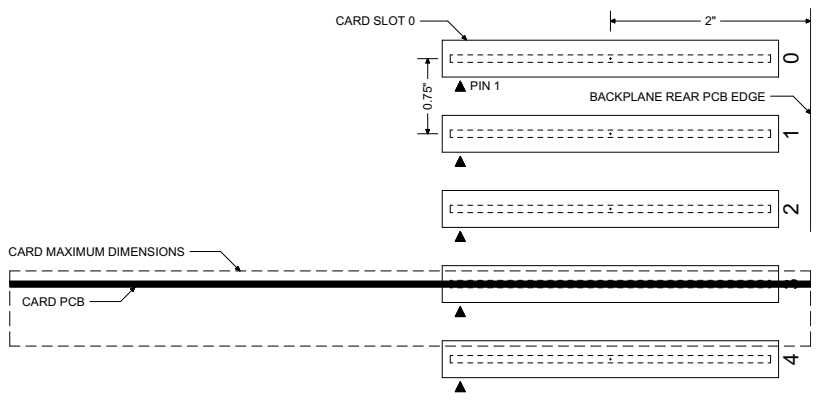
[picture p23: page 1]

BACKPLANE REAR PCB EDGE

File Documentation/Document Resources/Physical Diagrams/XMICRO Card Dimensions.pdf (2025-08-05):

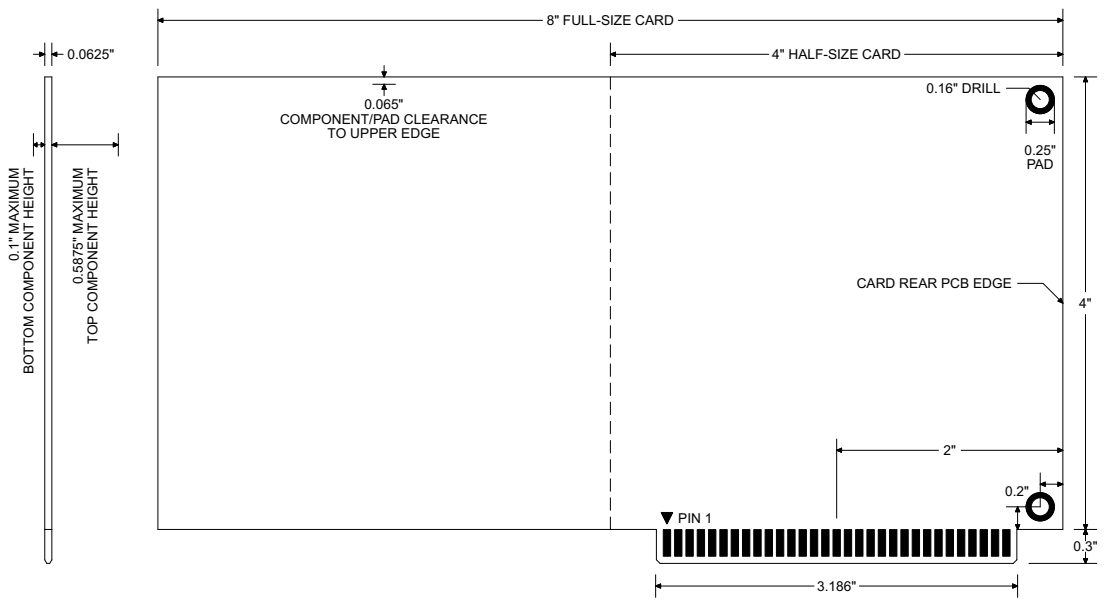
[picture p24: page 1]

CARD REAR PCB EDGE

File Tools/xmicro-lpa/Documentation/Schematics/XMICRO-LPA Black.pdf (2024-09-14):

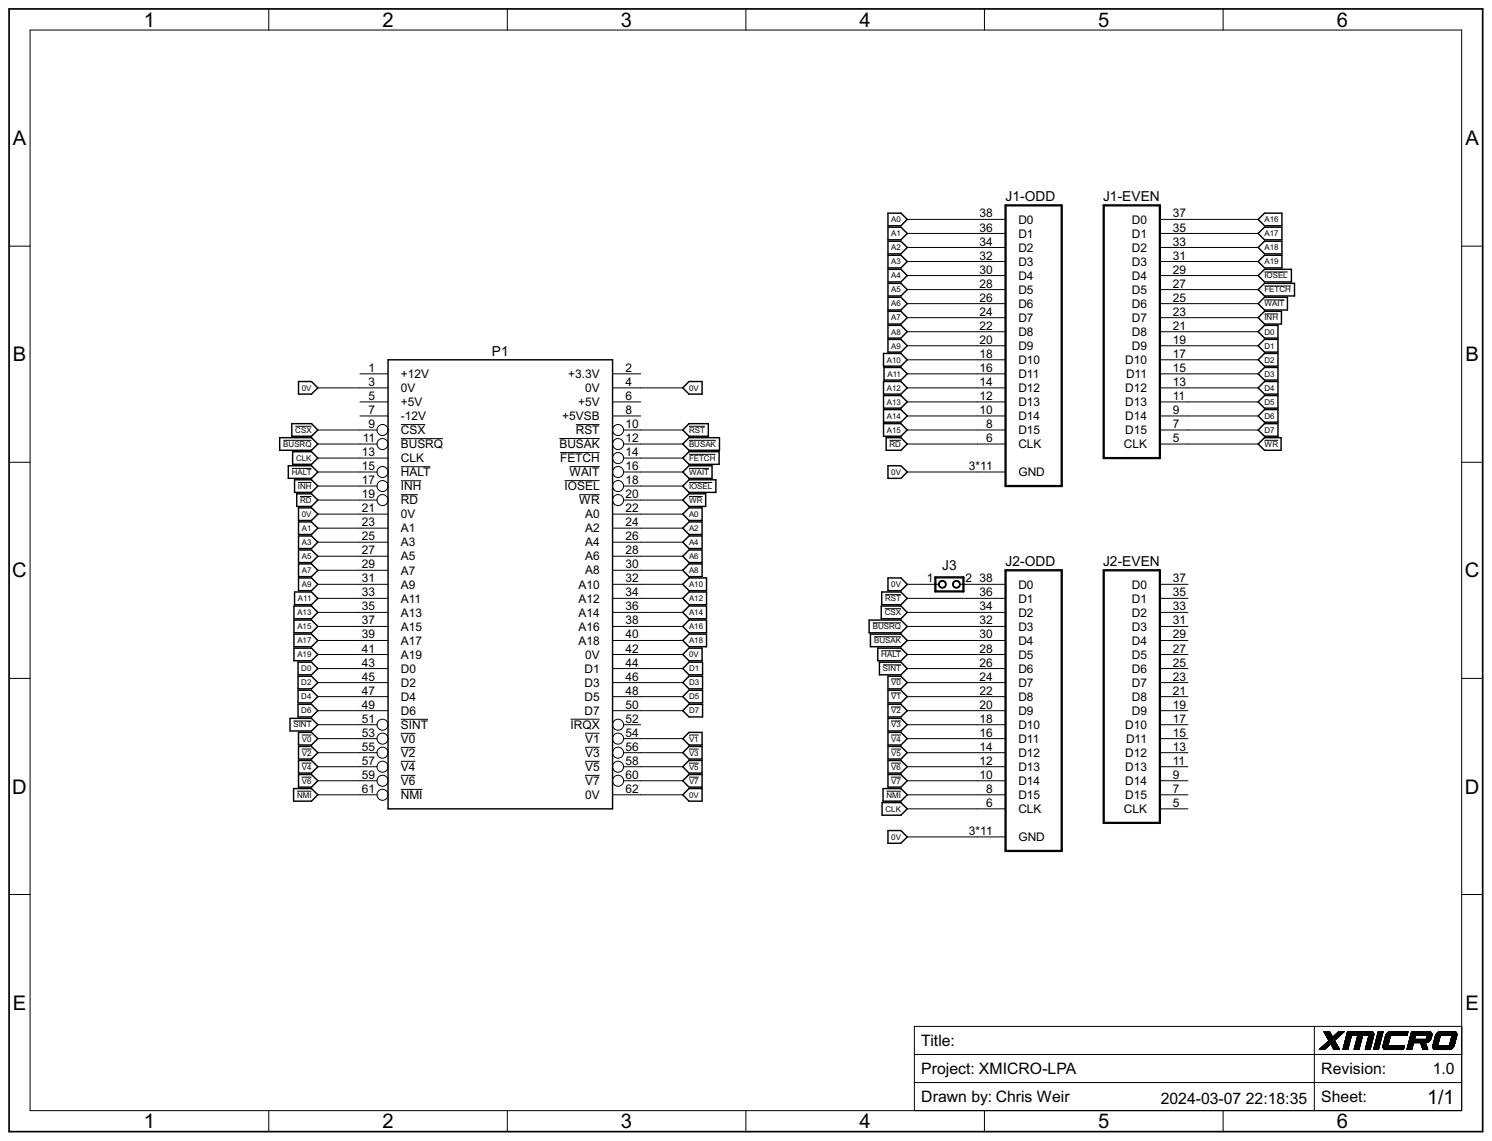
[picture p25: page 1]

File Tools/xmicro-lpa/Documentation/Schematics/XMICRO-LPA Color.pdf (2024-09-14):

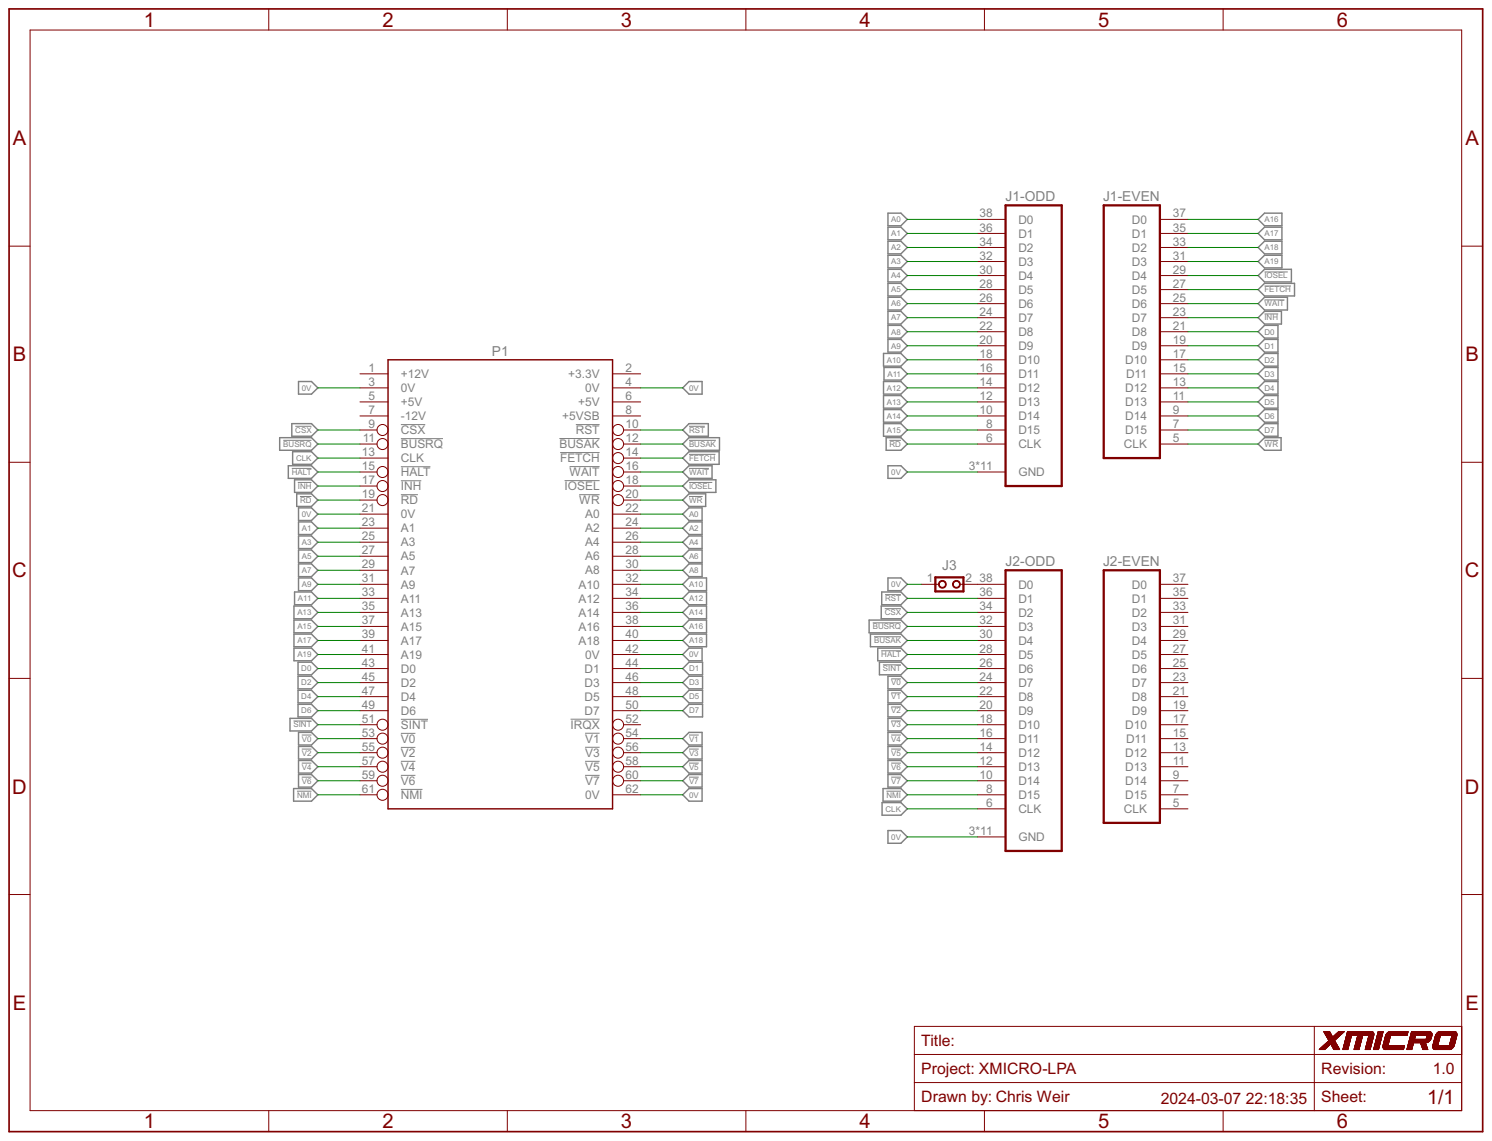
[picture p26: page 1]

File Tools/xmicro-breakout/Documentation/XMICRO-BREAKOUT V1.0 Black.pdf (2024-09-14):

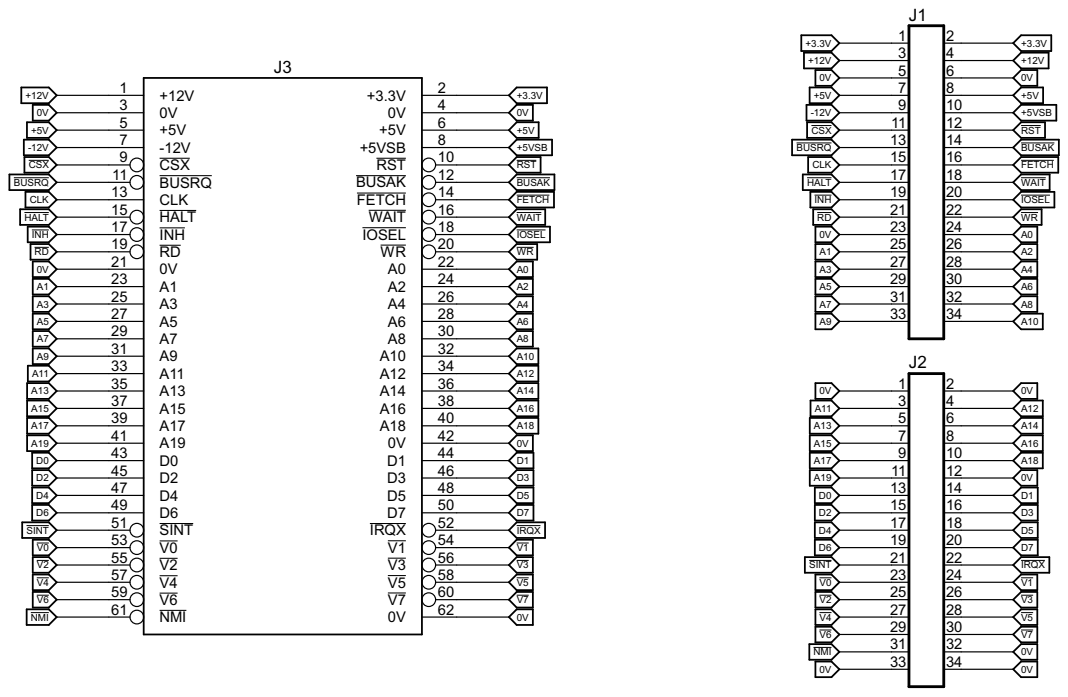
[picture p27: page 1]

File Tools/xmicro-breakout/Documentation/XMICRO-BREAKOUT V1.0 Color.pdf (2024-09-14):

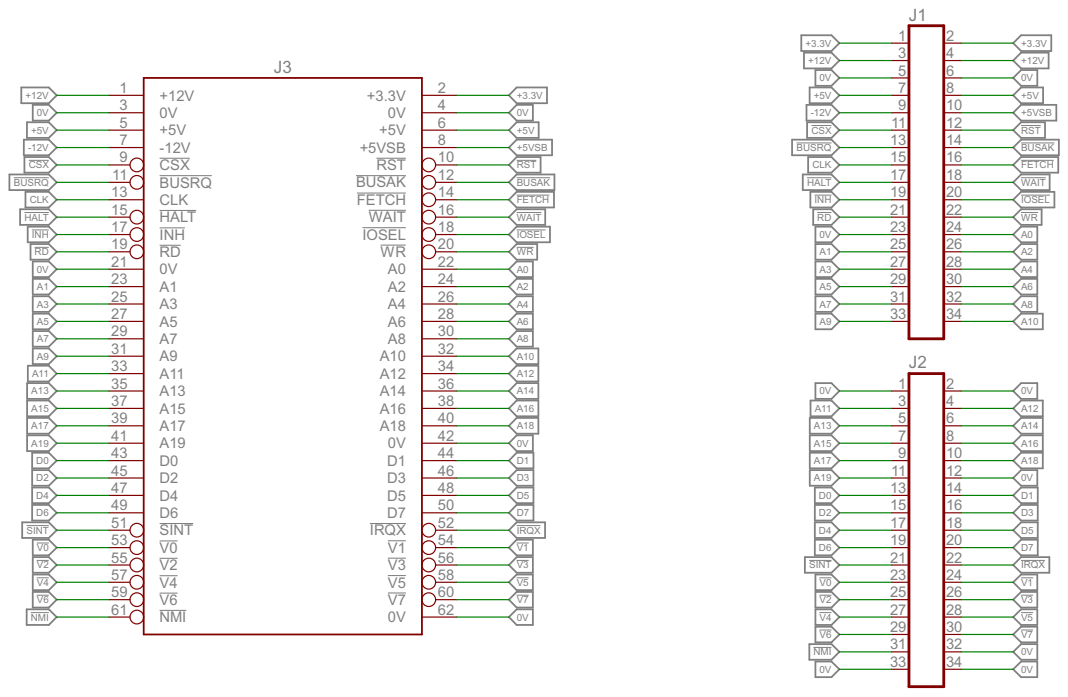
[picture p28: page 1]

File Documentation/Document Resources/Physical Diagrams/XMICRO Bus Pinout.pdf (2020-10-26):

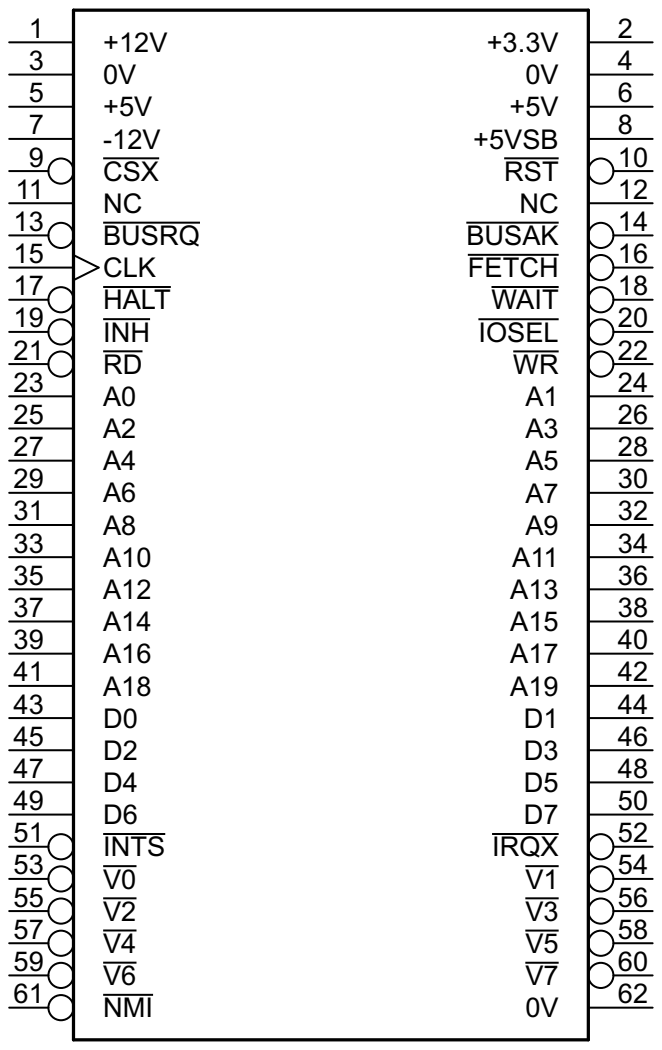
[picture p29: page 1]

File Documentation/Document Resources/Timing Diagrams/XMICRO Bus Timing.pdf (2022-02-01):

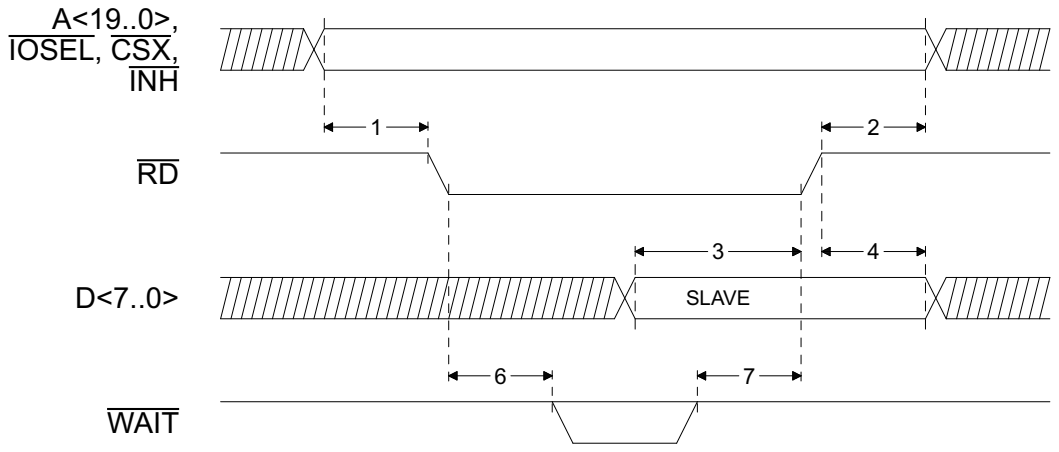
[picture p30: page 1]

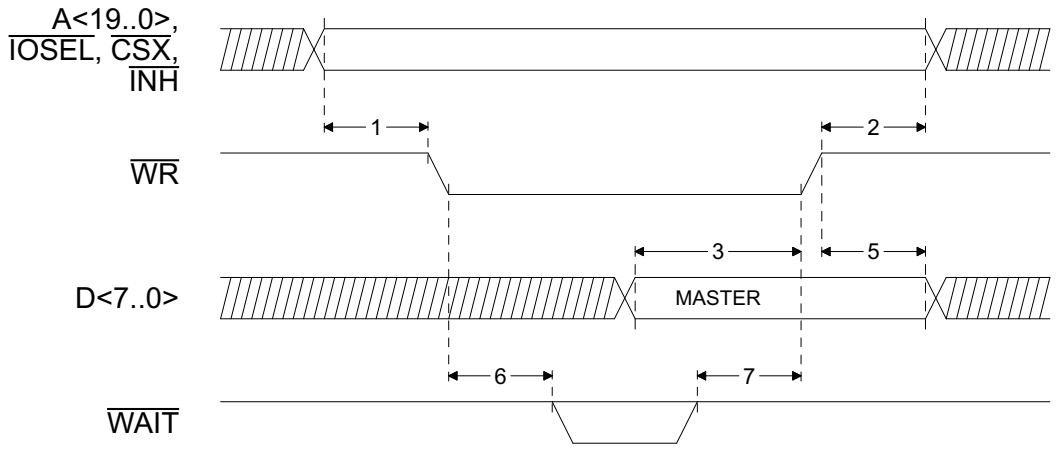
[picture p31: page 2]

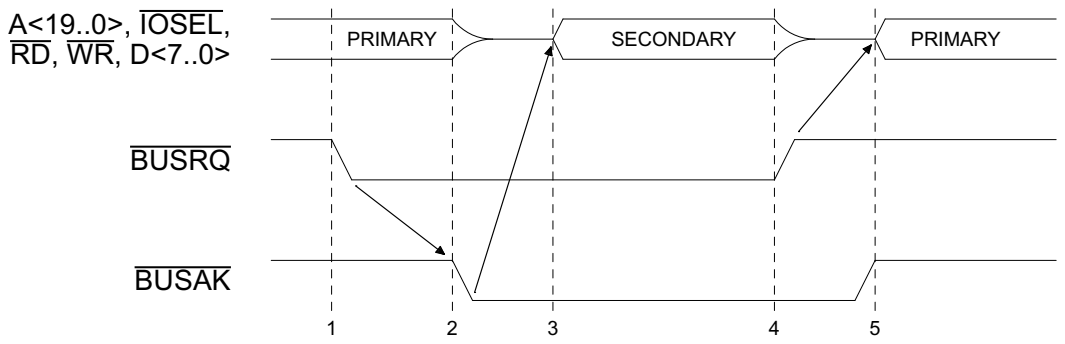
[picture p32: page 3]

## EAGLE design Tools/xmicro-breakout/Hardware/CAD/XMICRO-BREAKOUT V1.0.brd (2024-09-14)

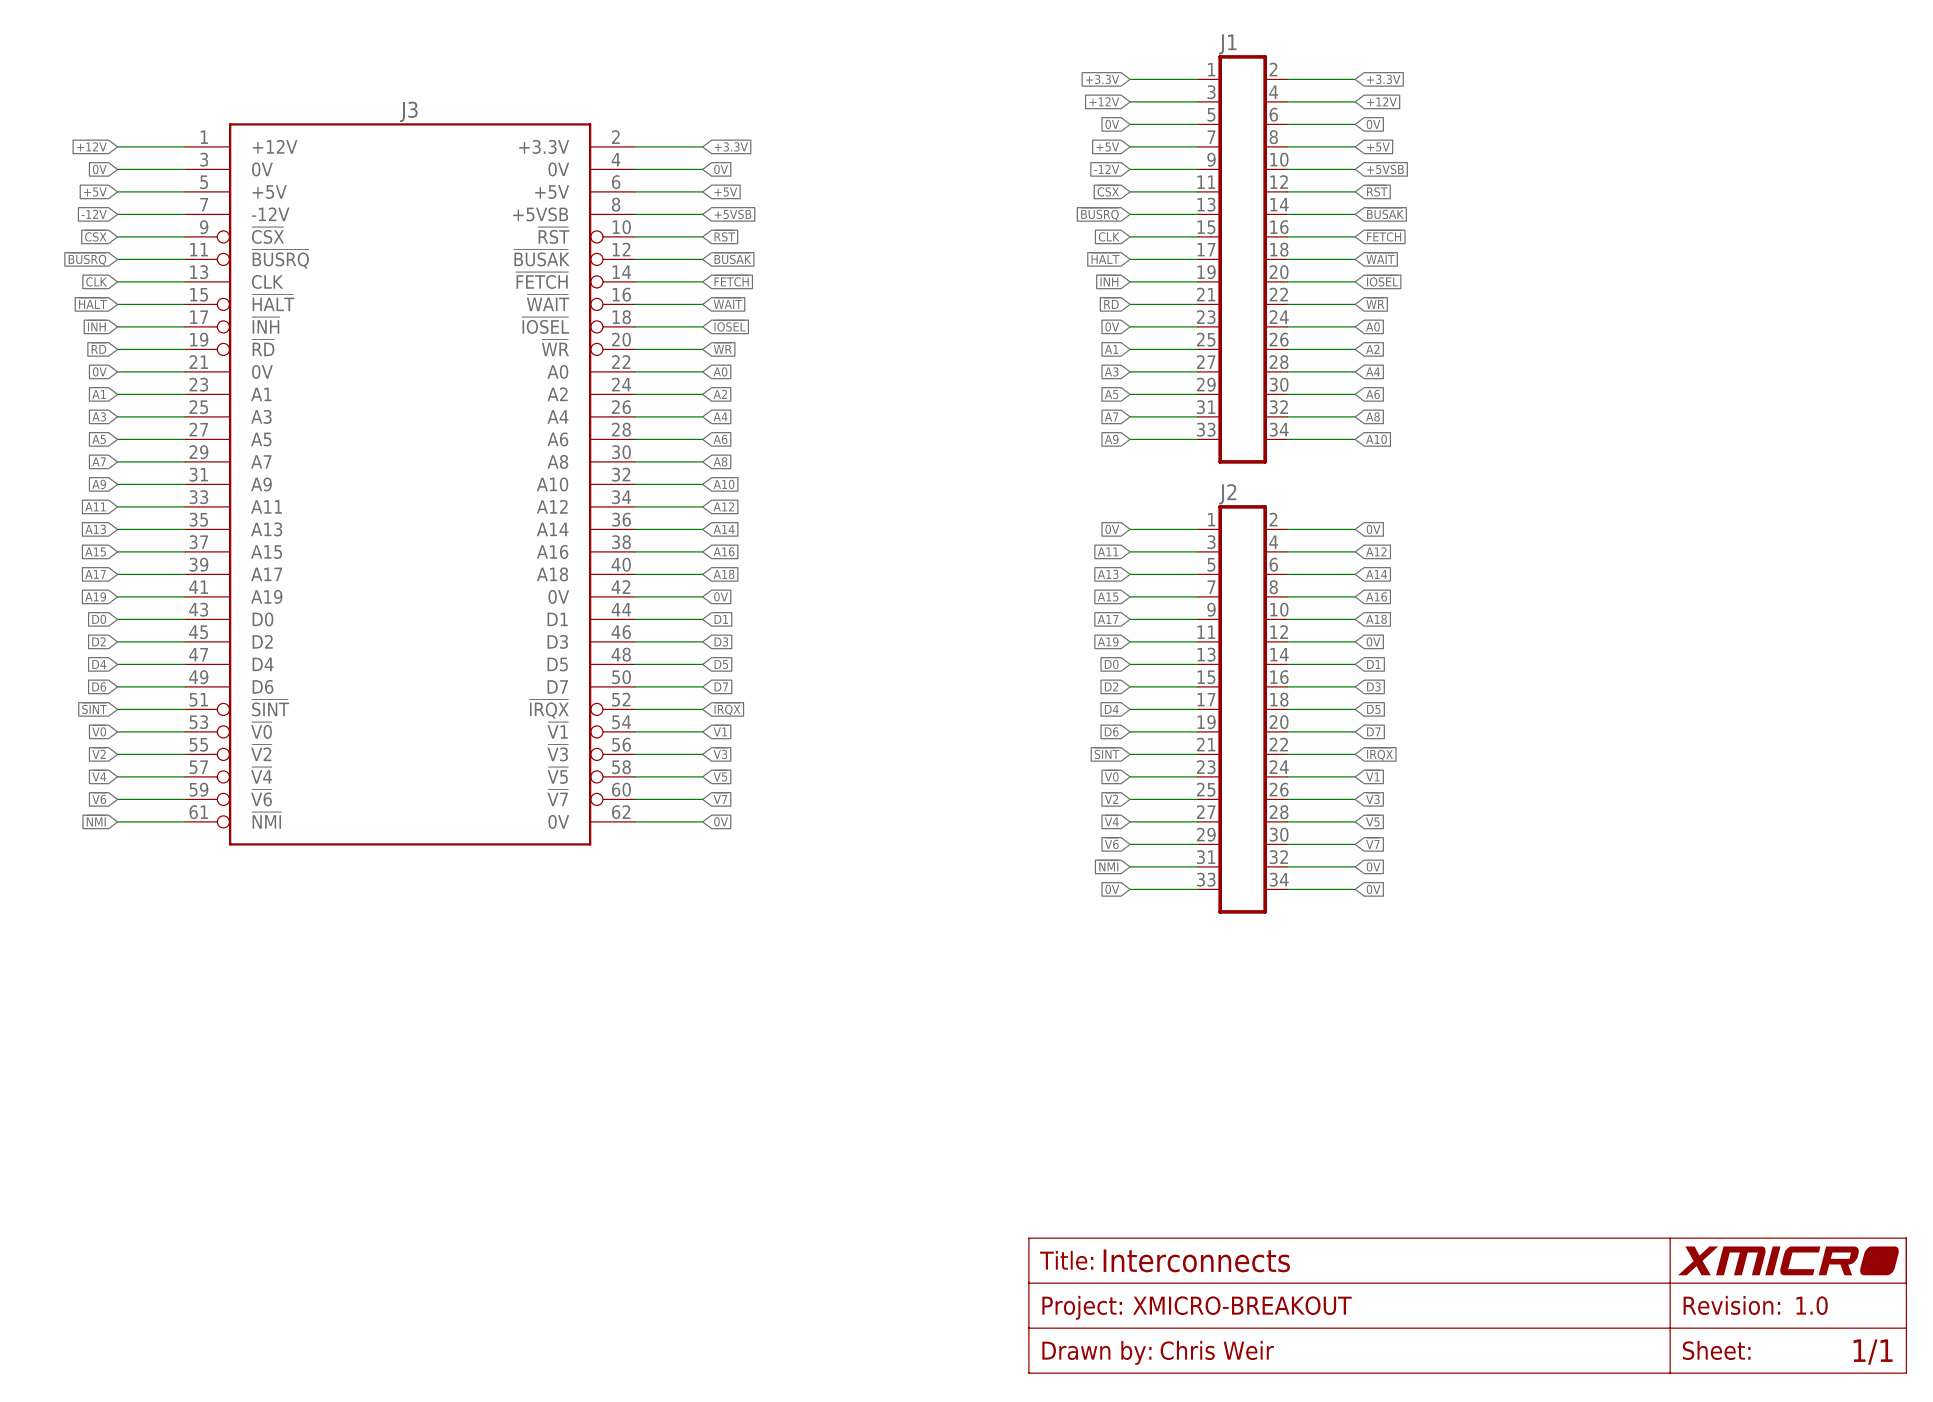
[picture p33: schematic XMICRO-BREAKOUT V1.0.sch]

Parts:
J1, J2: HDR-17X2; HDR-17X2S
J3: XMICRO-BUS-PHYSICAL-M; EDGE62M

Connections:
0V: J1.5, J1.6, J1.23, J2.1, J2.2, J2.12, J2.32, J2.33, J2.34, J3.3 (0V), J3.4 (0V), J3.21 (0V), J3.42 (0V), J3.62 (0V)
!BUSAK: J1.14, J3.12 (!BUSAK)
!BUSRQ: J1.13, J3.11 (!BUSRQ)
!CSX: J1.11, J3.9 (!CSX)
!FETCH: J1.16, J3.14 (!FETCH)
!HALT: J1.17, J3.15 (!HALT)
!INH: J1.19, J3.17 (!INH)
!IOSEL: J1.20, J3.18 (!IOSEL)
!IRQX: J2.22, J3.52 (!IRQX)
!NMI: J2.31, J3.61 (!NMI)
!RD: J1.21, J3.19 (!RD)
!RST: J1.12, J3.10 (!RST)
!SINT: J2.21, J3.51 (!SINT)
!V0: J2.23, J3.53 (!V0)
!V1: J2.24, J3.54 (!V1)
!V2: J2.25, J3.55 (!V2)
!V3: J2.26, J3.56 (!V3)
!V4: J2.27, J3.57 (!V4)
!V5: J2.28, J3.58 (!V5)
!V6: J2.29, J3.59 (!V6)
!V7: J2.30, J3.60 (!V7)
!WAIT: J1.18, J3.16 (!WAIT)
!WR: J1.22, J3.20 (!WR)
+3.3V: J1.1, J1.2, J3.2 (+3.3V)
+5V: J1.7, J1.8, J3.5 (+5V), J3.6 (+5V)
+5VSB: J1.10, J3.8 (+5VSB)
+12V: J1.3, J1.4, J3.1 (+12V)
-12V: J1.9, J3.7 (-12V)
A0: J1.24, J3.22 (A0)
A1: J1.25, J3.23 (A1)
A2: J1.26, J3.24 (A2)
A3: J1.27, J3.25 (A3)
A4: J1.28, J3.26 (A4)
A5: J1.29, J3.27 (A5)
A6: J1.30, J3.28 (A6)
A7: J1.31, J3.29 (A7)
A8: J1.32, J3.30 (A8)
A9: J1.33, J3.31 (A9)
A10: J1.34, J3.32 (A10)
A11: J2.3, J3.33 (A11)
A12: J2.4, J3.34 (A12)
A13: J2.5, J3.35 (A13)
A14: J2.6, J3.36 (A14)
A15: J2.7, J3.37 (A15)
A16: J2.8, J3.38 (A16)
A17: J2.9, J3.39 (A17)
A18: J2.10, J3.40 (A18)
A19: J2.11, J3.41 (A19)
CLK: J1.15, J3.13 (CLK)
D0: J2.13, J3.43 (D0)
D1: J2.14, J3.44 (D1)
D2: J2.15, J3.45 (D2)
D3: J2.16, J3.46 (D3)
D4: J2.17, J3.47 (D4)
D5: J2.18, J3.48 (D5)
D6: J2.19, J3.49 (D6)
D7: J2.20, J3.50 (D7)

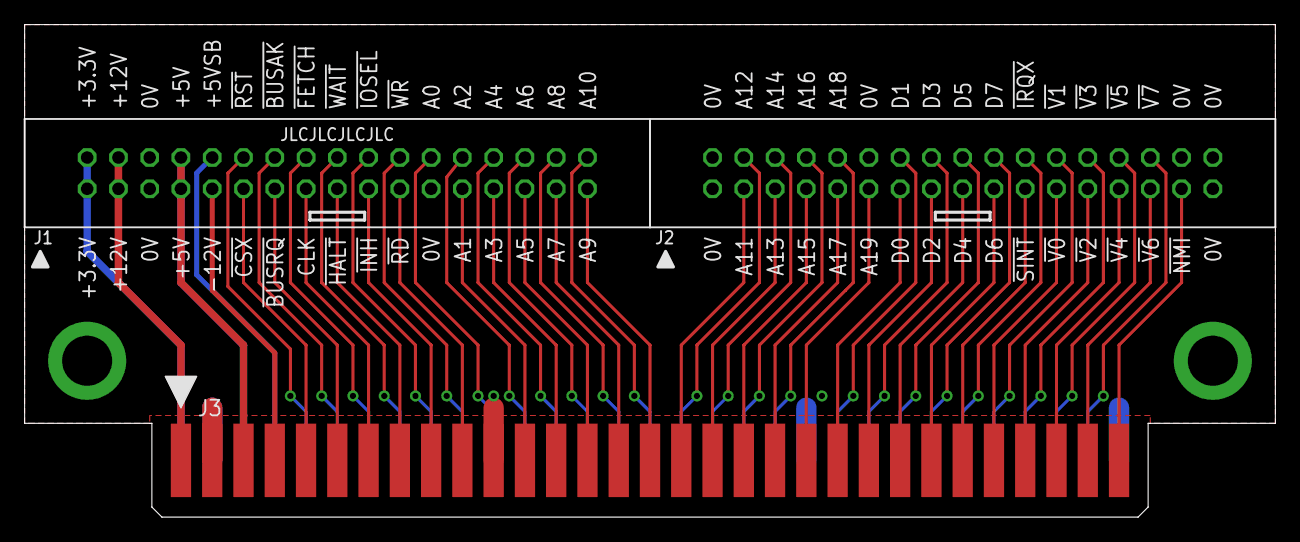
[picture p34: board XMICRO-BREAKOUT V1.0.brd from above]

Board: 2 copper layers, 101.6 x 40.0 mm, 3 parts (0 on the bottom side), 57 nets.

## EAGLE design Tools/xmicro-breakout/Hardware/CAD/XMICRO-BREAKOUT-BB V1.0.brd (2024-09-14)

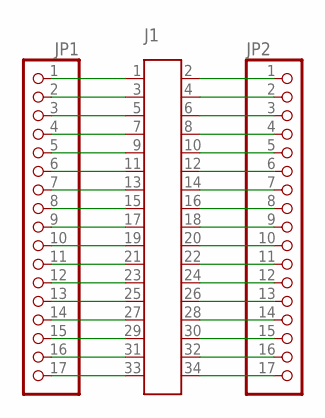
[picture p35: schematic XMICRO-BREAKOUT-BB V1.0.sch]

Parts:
J1: HDR-17X2; HDR-17X2S
JP1, JP2: PINHD-1X17; 1X17

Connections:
unnamed: J1.1, JP1.1
unnamed: J1.3, JP1.2
unnamed: J1.5, JP1.3
unnamed: J1.7, JP1.4
unnamed: J1.9, JP1.5
unnamed: J1.11, JP1.6
unnamed: J1.13, JP1.7
unnamed: J1.15, JP1.8
unnamed: J1.17, JP1.9
unnamed: J1.19, JP1.10
unnamed: J1.21, JP1.11
unnamed: J1.23, JP1.12
unnamed: J1.25, JP1.13
unnamed: J1.27, JP1.14
unnamed: J1.29, JP1.15
unnamed: J1.31, JP1.16
unnamed: J1.33, JP1.17
unnamed: J1.2, JP2.1
unnamed: J1.4, JP2.2
unnamed: J1.6, JP2.3
unnamed: J1.8, JP2.4
unnamed: J1.10, JP2.5
unnamed: J1.12, JP2.6
unnamed: J1.14, JP2.7
unnamed: J1.16, JP2.8
unnamed: J1.18, JP2.9
unnamed: J1.20, JP2.10
unnamed: J1.22, JP2.11
unnamed: J1.24, JP2.12
unnamed: J1.26, JP2.13
unnamed: J1.28, JP2.14
unnamed: J1.30, JP2.15
unnamed: J1.32, JP2.16
unnamed: J1.34, JP2.17

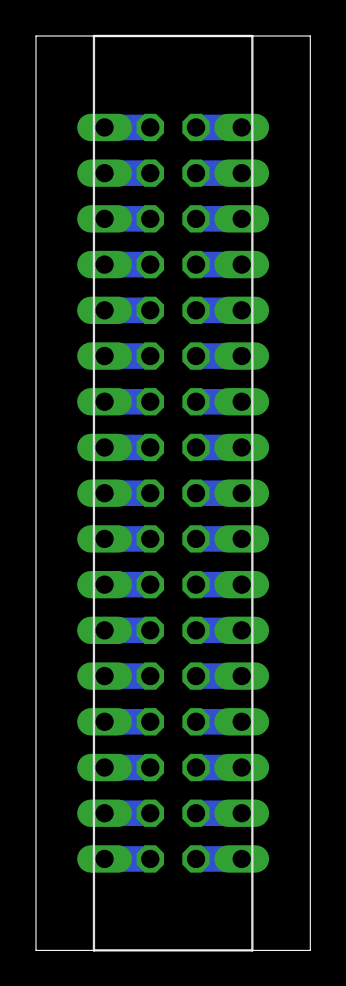
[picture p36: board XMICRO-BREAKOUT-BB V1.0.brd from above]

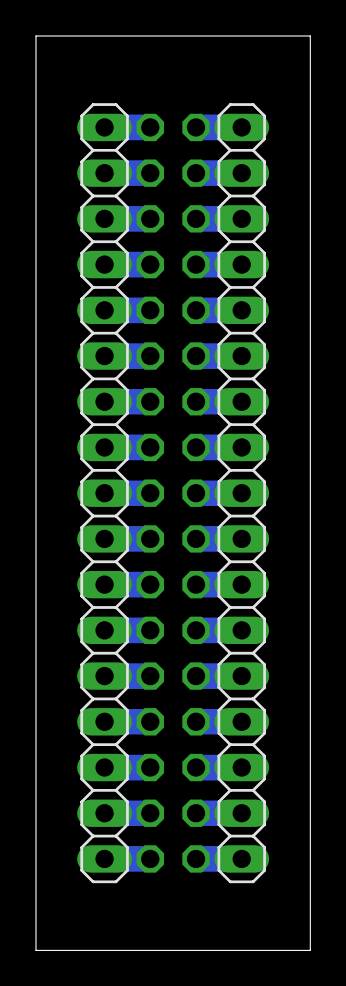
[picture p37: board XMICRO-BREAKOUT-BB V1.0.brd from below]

Board: 2 copper layers, 15.2 x 50.8 mm, 3 parts (2 on the bottom side), 34 nets.

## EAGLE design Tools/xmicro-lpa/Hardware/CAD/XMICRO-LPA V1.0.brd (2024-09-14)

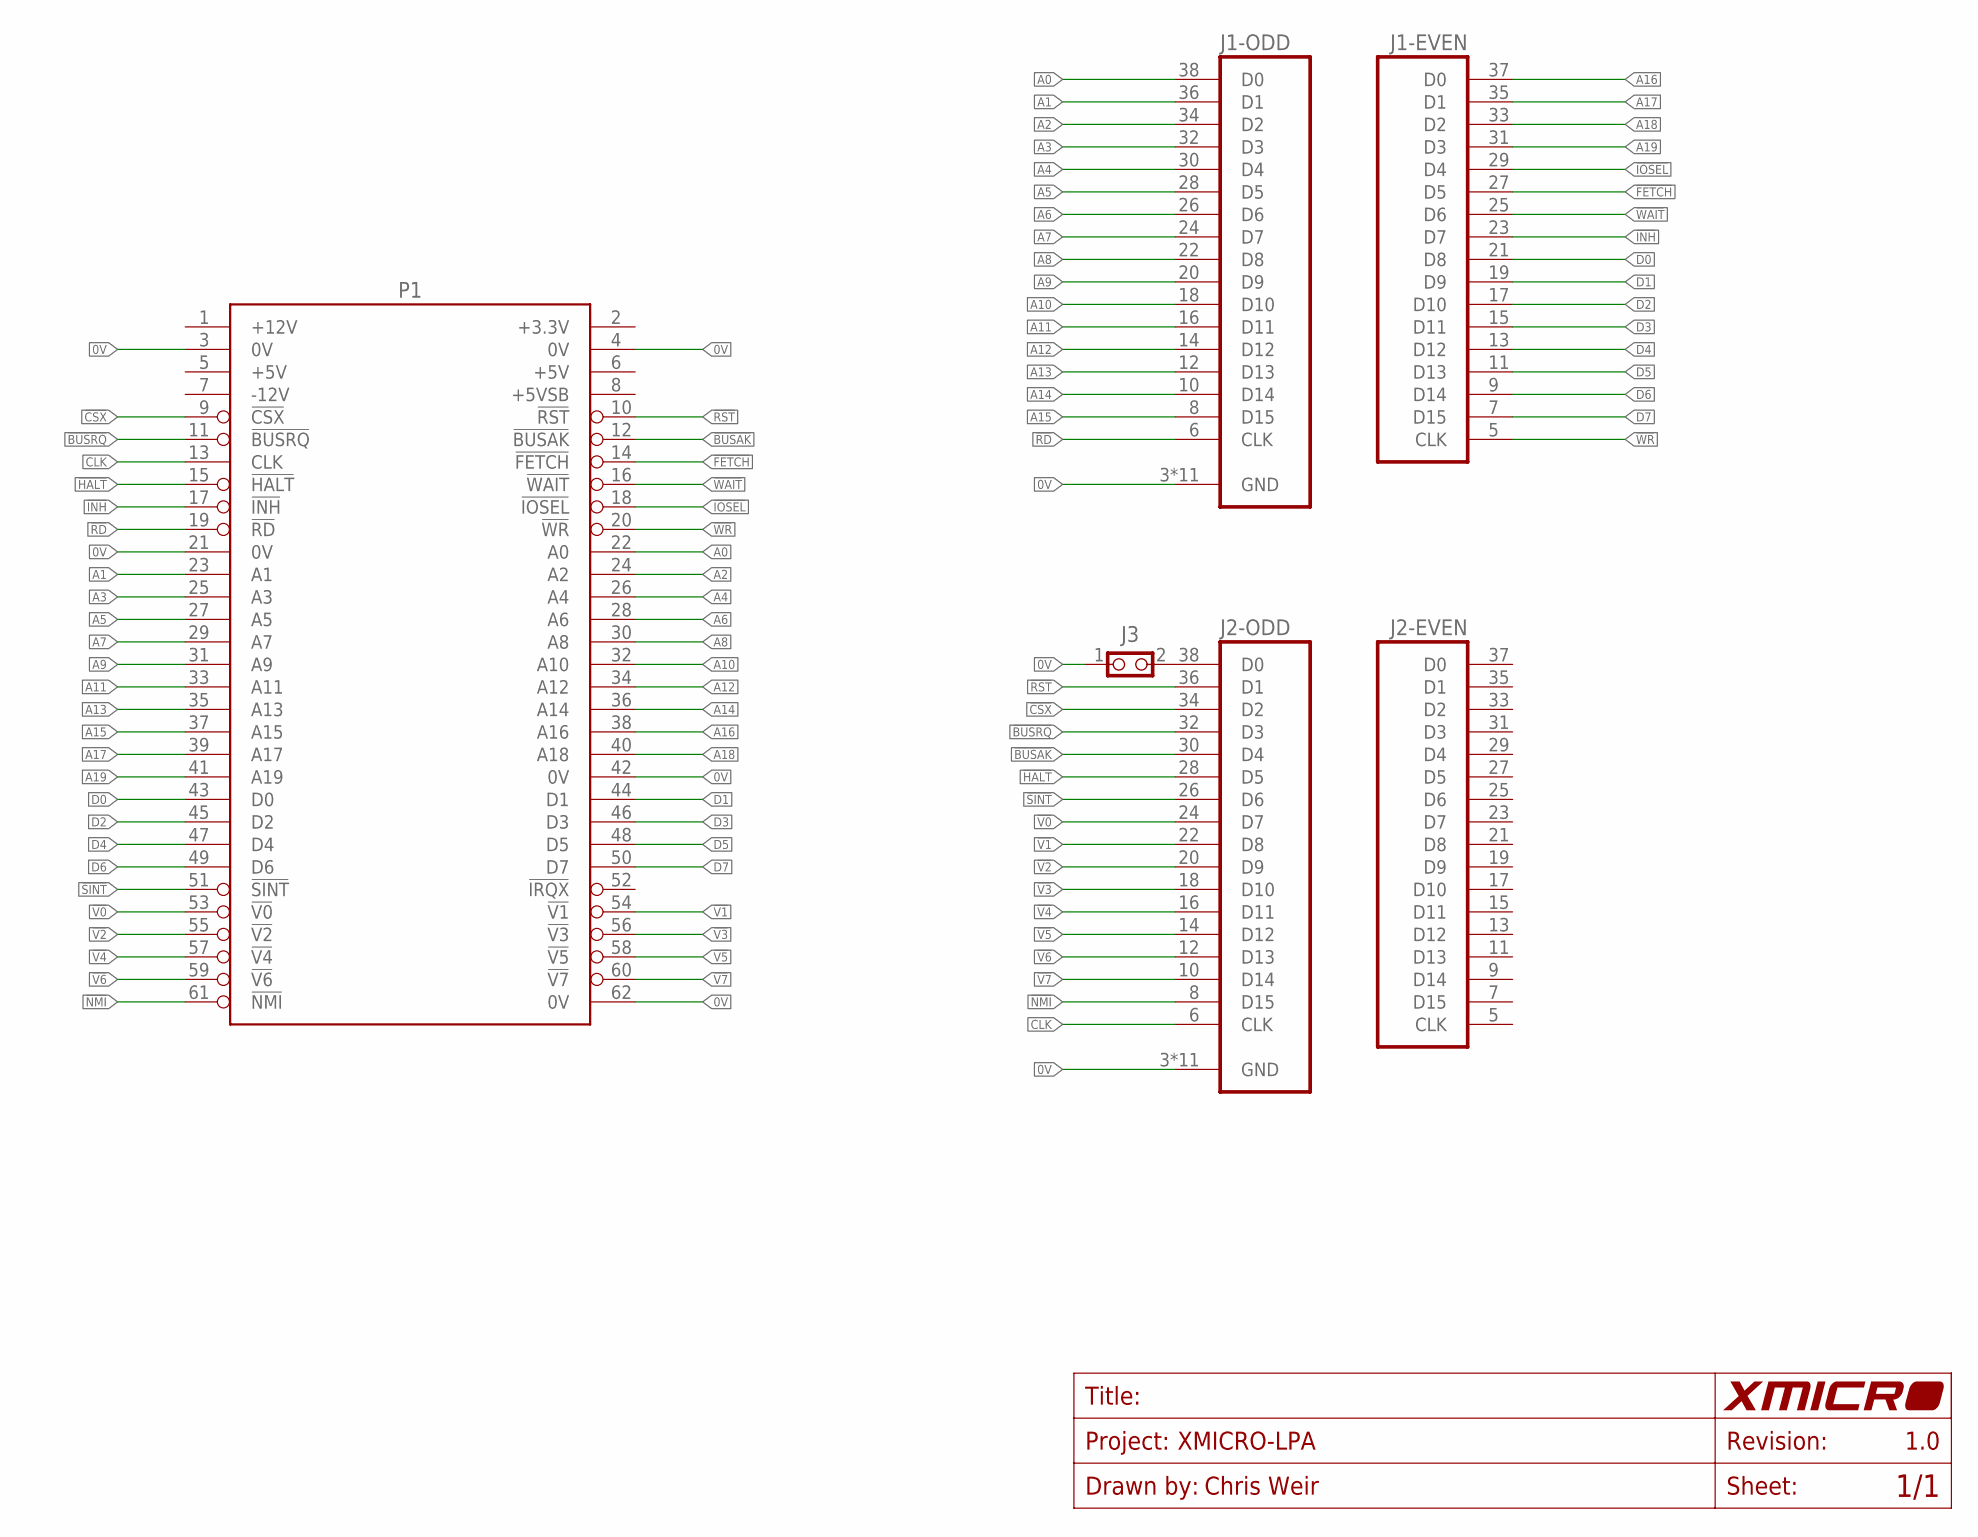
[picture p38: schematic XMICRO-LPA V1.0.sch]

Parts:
J1, J2: LA-34MEB; 5767089-1B
J3: 1X2-THRU; 1X2
P1: XMICRO-BUS-PHYSICAL-M; EDGE62M

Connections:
0V: J1.3 (GND), J1.G1 (GND), J1.G2 (GND), J1.G3 (GND), J1.G4 (GND), J1.G5 (GND), J1.G6 (GND), J1.G7 (GND), J1.G8 (GND), J1.G9 (GND), J1.G10 (GND), J2.3 (GND), J2.G1 (GND), J2.G2 (GND), J2.G3 (GND), J2.G4 (GND), J2.G5 (GND), J2.G6 (GND), J2.G7 (GND), J2.G8 (GND), J2.G9 (GND), J2.G10 (GND), J3.1, P1.3 (0V), P1.4 (0V), P1.21 (0V), P1.42 (0V), P1.62 (0V)
!BUSAK: J2.30 (D4), P1.12 (!BUSAK)
!BUSRQ: J2.32 (D3), P1.11 (!BUSRQ)
!CSX: J2.34 (D2), P1.9 (!CSX)
!FETCH: J1.27 (D5), P1.14 (!FETCH)
!HALT: J2.28 (D5), P1.15 (!HALT)
!INH: J1.23 (D7), P1.17 (!INH)
!IOSEL: J1.29 (D4), P1.18 (!IOSEL)
!NMI: J2.8 (D15), P1.61 (!NMI)
!RD: J1.6 (CLK), P1.19 (!RD)
!RST: J2.36 (D1), P1.10 (!RST)
!SINT: J2.26 (D6), P1.51 (!SINT)
!V0: J2.24 (D7), P1.53 (!V0)
!V1: J2.22 (D8), P1.54 (!V1)
!V2: J2.20 (D9), P1.55 (!V2)
!V3: J2.18 (D10), P1.56 (!V3)
!V4: J2.16 (D11), P1.57 (!V4)
!V5: J2.14 (D12), P1.58 (!V5)
!V6: J2.12 (D13), P1.59 (!V6)
!V7: J2.10 (D14), P1.60 (!V7)
!WAIT: J1.25 (D6), P1.16 (!WAIT)
!WR: J1.5 (CLK), P1.20 (!WR)
A0: J1.38 (D0), P1.22 (A0)
A1: J1.36 (D1), P1.23 (A1)
A2: J1.34 (D2), P1.24 (A2)
A3: J1.32 (D3), P1.25 (A3)
A4: J1.30 (D4), P1.26 (A4)
A5: J1.28 (D5), P1.27 (A5)
A6: J1.26 (D6), P1.28 (A6)
A7: J1.24 (D7), P1.29 (A7)
A8: J1.22 (D8), P1.30 (A8)
A9: J1.20 (D9), P1.31 (A9)
A10: J1.18 (D10), P1.32 (A10)
A11: J1.16 (D11), P1.33 (A11)
A12: J1.14 (D12), P1.34 (A12)
A13: J1.12 (D13), P1.35 (A13)
A14: J1.10 (D14), P1.36 (A14)
A15: J1.8 (D15), P1.37 (A15)
A16: J1.37 (D0), P1.38 (A16)
A17: J1.35 (D1), P1.39 (A17)
A18: J1.33 (D2), P1.40 (A18)
A19: J1.31 (D3), P1.41 (A19)
CLK: J2.6 (CLK), P1.13 (CLK)
D0: J1.21 (D8), P1.43 (D0)
D1: J1.19 (D9), P1.44 (D1)
D2: J1.17 (D10), P1.45 (D2)
D3: J1.15 (D11), P1.46 (D3)
D4: J1.13 (D12), P1.47 (D4)
D5: J1.11 (D13), P1.48 (D5)
D6: J1.9 (D14), P1.49 (D6)
D7: J1.7 (D15), P1.50 (D7)
unnamed: J2.38 (D0), J3.2

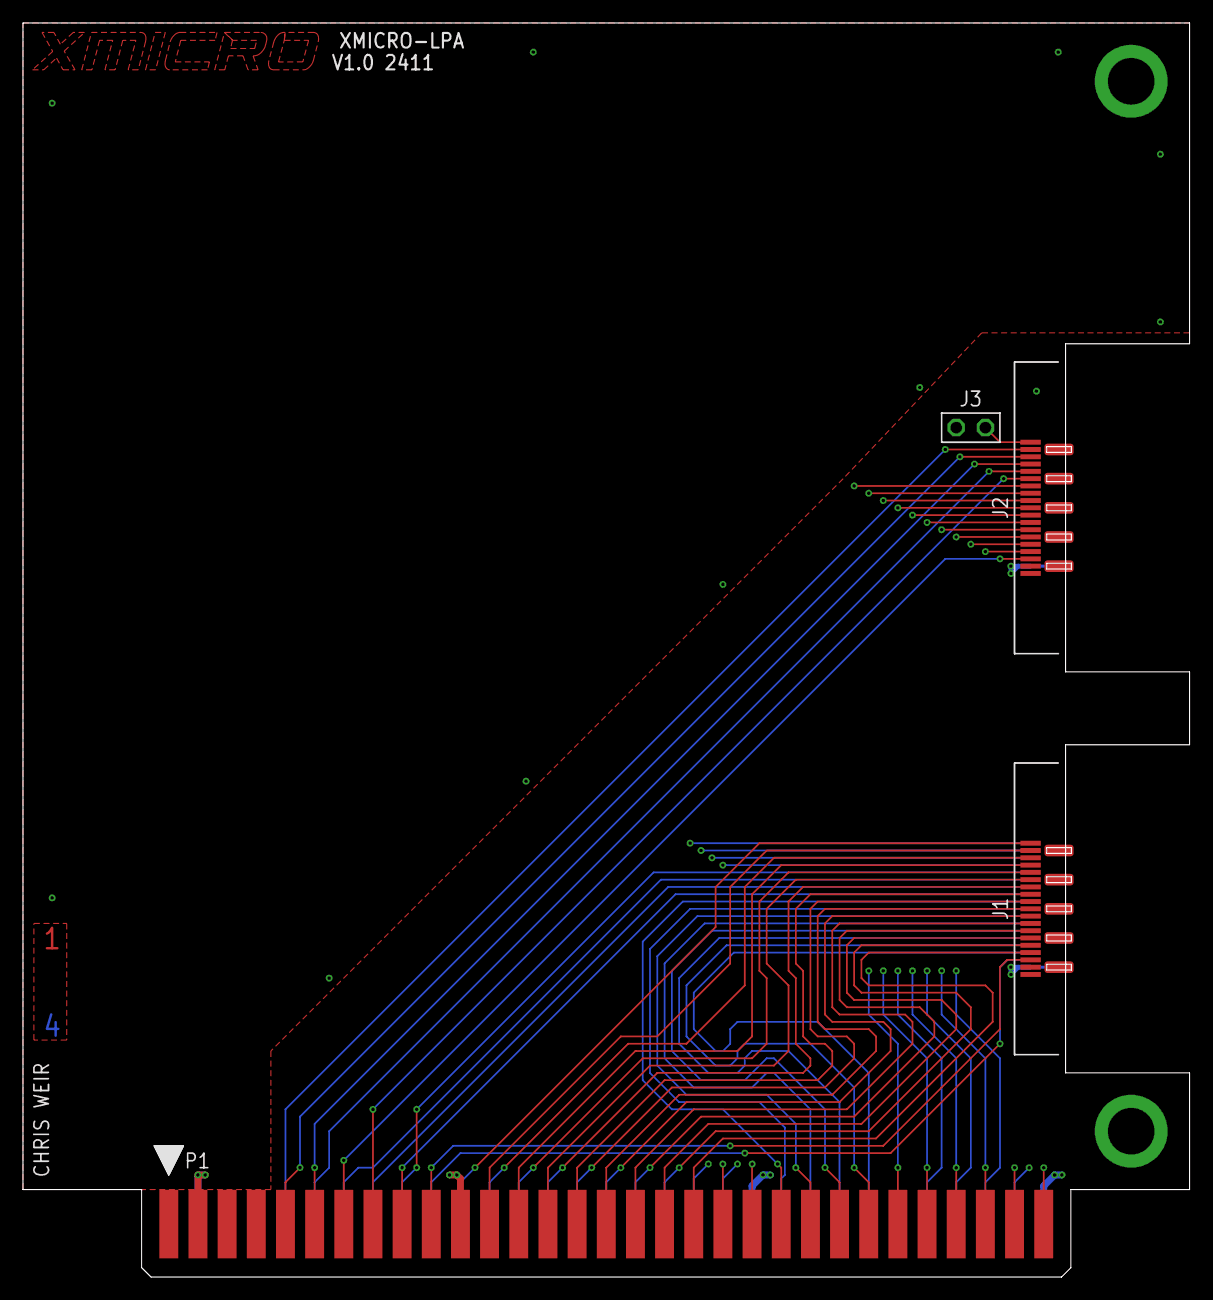
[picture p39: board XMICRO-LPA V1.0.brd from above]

Board: 4 copper layers, 101.6 x 109.2 mm, 4 parts (0 on the bottom side), 52 nets.

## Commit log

2018-10-07 Added dimensional drawings for cards
    [XMICRO Card Dimensions.brd]
2018-10-08 Added backplane dimensions and updated the specification document
    [XMICRO Backplane Dimenisons.brd, XMICRO Card Dimensions.brd]
2018-10-08 Updated specification document and dimensional drawings
    [XMICRO Backplane Dimenisons.brd, XMICRO Card Dimensions.brd]
2018-11-30 Updated NMI signal and related DMA descriptions
2019-03-04 Updated physical dimensions (PCB rear edge to chassis)
    [XMICRO Backplane Dimenisons.brd, XMICRO Card Dimensions.brd]
2019-03-04 Updated pinout - Replaced CLKAUX with /IO
    [XMICRO Bus Pinout.sch]
2019-03-07 Fixed dimensional drawings
    [XMICRO Backplane Dimenisons.brd]
2019-03-08 Fixed dimensional drawings and pinout diagram
    [XMICRO Backplane Dimenisons.brd, XMICRO Card Dimensions.brd]
2019-03-24 Moved bus tools into this repository.
    [XMICRO-BREAKOUT-BREADBOARD.brd, XMICRO-BREAKOUT-BREADBOARD.sch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]
2019-03-24 Fixed an issue with the XMICRO-EXT riser card.
    [XMICRO-EXT.brd, XMICRO-EXT.sch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]
2019-03-24 Changed IO signal name to IOSEL
    [XMICRO Bus Pinout.sch]
2019-03-24 Added XMICRO-PROTO card to tools
    [XMICRO-PROTO.brd, XMICRO-PROTO.sch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]
2019-03-24 Fixed tools with new IOSEL signal
    [XMICRO-BREAKOUT-CARD.brd, XMICRO-BREAKOUT-CARD.sch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]
2019-10-28 XMICRO-EXT: Modified connector footprint
    [XMICRO-EXT.brd, XMICRO-EXT.sch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]
2020-07-06 Updated specification
    [XMICRO Backplane Dimenisons.brd, XMICRO Bus Pinout.sch, XMICRO Card Dimensions.brd]
2020-07-19 Updating bus specification
    [XMICRO Backplane Dimenisons.brd, XMICRO Card Dimensions.brd]
2020-10-26 Updated to V0.4 - modified bus connector pinout
    [XMICRO Bus Pinout.sch]
2020-12-16 Added timing diagrams
    [XMICRO Bus Timing.sch]
2021-01-02 Updated timing specs, changed physical drawings font
    [XMICRO Backplane Dimenisons.brd, XMICRO Bus Pinout.sch, XMICRO Bus Timing.sch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]
2021-02-08 Changed bus connector pinout
2021-05-01 Updated bus arbitration description and diagram
    [XMICRO Bus Timing.sch]
2022-05-11 Updated physical specifications for the XMICRO-CASE project
    [XMICRO Backplane Dimenisons.brd, XMICRO Card Dimensions.brd]
2024-09-14 Added XMICRO-LPA documentation and hardware
    [XMICRO-LPA Shield V1.0.brd, XMICRO-LPA Skew.csv, XMICRO-LPA Skew.ods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]
2024-09-14 Removed XMICRO-PROTO because small-run manufacturers refuse to make it
    [XMICRO-PROTO.brd, XMICRO-PROTO.sch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]
2024-09-14 Updated hardware tools to Gen 2
    [XMICRO-BREAKOUT V1.0.brd, XMICRO-BREAKOUT V1.0.sch, XMICRO-BREAKOUT-BB V1.0.brd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]
2025-08-05 Minor documentation improvements
    [XMICRO Backplane Dimenisons.brd, XMICRO Card Dimensions.brd]
